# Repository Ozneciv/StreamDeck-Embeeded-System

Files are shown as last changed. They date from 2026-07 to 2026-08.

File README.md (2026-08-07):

# ⌨️ StreamDeck Embedded System

> Periférico de entrada dedicado (*Macro Pad / Stream Deck*) de 9 teclas mecânicas baseado no microcontrolador ARM Cortex-M3 (STM32F103C8T6), desenvolvido com arquitetura orientada a interrupção de timer (100 Hz), comunicação USB Custom HID nativa e PCB em camada única.

---

## 📌 Visão Geral

Este repositório contém o código-fonte do firmware em C (STM32CubeIDE), projeto de hardware no KiCad (PCB Single-Layer `B.Cu` e arquivos Gerber), modelos 3D em STL da carcaça e o relatório técnico para a disciplina de **Sistemas Embarcados I** da **Universidade Federal de Uberlândia (UFU / FEELT)**.

---

## 🌟 Principais Características

- **⚡ Zero Polling:** Varredura da matriz 3x3 realizada por **Interrupção por Timer de Hardware (TIM2 a 100 Hz / 10 ms)** com repouso em baixo consumo (`__WFI()`).
- **🔄 Re-enumeração USB Automática:** Reset de software no pino USB D+ (`PA12`) na inicialização para identificação instantânea no SO após gravações.
- **🛡️ Anti-Ghosting:** Matriz 3x3 associada a 9 diodos $1\text{N}4148$.
- **🔌 Classe USB Custom HID:** Envio nativo de relatórios IN de 8 Bytes com atalhos de teclado (F13 a F21) e suporte a relatórios OUT bidirecionais.
- **📐 PCB Face Simples:** Placa projetada no KiCad em camada única (`B.Cu`) com trilhas reforçadas ($0.8\,\text{mm}$ a $1.2\,\text{mm}$) para fabricação por corrosão artesanal.
- **📦 Carcaça 3D:** Gabinete personalizado impresso em 3D com insertos roscados M3.

---

## 📷 Fotos do Projeto

<div align="center">

| Protótipo Finalizado | Montagem Física Interna |
| :---: | :---: |
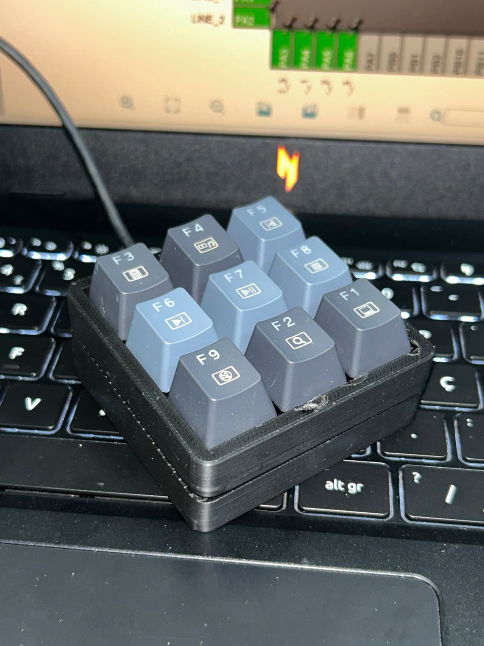
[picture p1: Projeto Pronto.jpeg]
Protótipo Finalizado
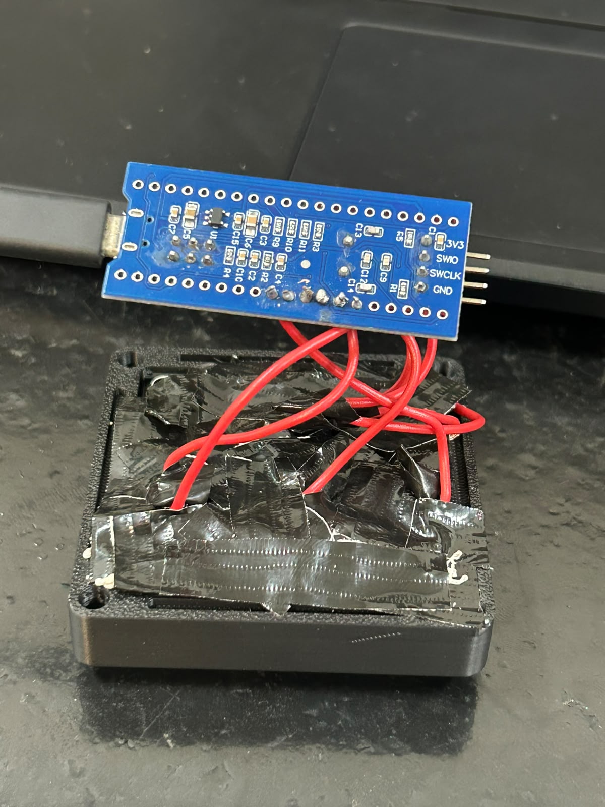
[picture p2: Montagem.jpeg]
Montagem Física
|  |  |

</div>

---

## 🔌 Mapeamento de Pinos (Pinout STM32F103C8T6)

| Pino | Função | Modo GPIO / Periférico |
| :---: | :---: | :---: |
| **PA1, PA2, PA3** | Linhas 1 a 3 da Matriz | `GPIO_MODE_OUTPUT_OD` (Open Drain) |
| **PA4, PA5, PA6** | Colunas 1 a 3 da Matriz | `GPIO_MODE_INPUT` (Pull-Up Interno) |
| **PA11 / PA12** | USB D- / USB D+ | Periférico USB Custom HID |
| **PA13 / PA14** | SWDIO / SWCLK | Interface de Gravação e Depuração ST-LINK |

---

## 📂 Estrutura do Repositório

```text
├── streamdeck bluepill/        # Projeto STM32CubeIDE (Firmware C e arquivo .ioc)
├── PCB_FINAL/                  # Arquivos de fabricação KiCad e Gerbers finais
├── 3D/                         # Arquivos e modelos 3D STL do gabinete e teclas
├── dashboard/                  # Painel web interativo para testes e telemetria
├── StreamDeck_SEMB.pdf         # Relatório Técnico & Memorial Descritivo (PDF)
├── relatorio_streamdeck.tex    # Código-fonte em LaTeX do relatório
└── README.md                   # Documentação do projeto
```

---

## 🛠️ Como Compilar e Gravar o Firmware

1. **Requisitos:**
   - [STM32CubeIDE](https://www.st.com/en/development-tools/stm32cubeide.html) (v1.10 ou superior)
   - Gravador ST-LINK V2 ou via USB DFU Bootloader
2. **Passos:**
   - Abra o STM32CubeIDE e importe a pasta `streamdeck bluepill`.
   - Compile o projeto (`Project -> Build Project` ou `Ctrl+B`).
   - Conecte o ST-LINK à placa Blue Pill (SWDIO: PA13, SWCLK: PA14, GND, 3.3V).
   - Clique em `Run -> Debug` ou `Flash` para gravar o arquivo `.elf`.

---

## 👥 Equipe (Discentes / FEELT UFU)

- **Bruna de Jesus Silva** — `12021ETE007`
- **Gustavo Martins Ribeiro Moura** — `12111ETE002`
- **Mateus Henrique Gonçalves** — `12311ECP021`
- **Vicenzo De Marco Olivalves** — `12421ECP006`

**Docente Responsável:** Prof. Jeovane Vicente de Sousa  
**Curso:** Engenharia de Computação & Engenharia Eletrônica — UFU / FEELT  
**Ano:** 2026

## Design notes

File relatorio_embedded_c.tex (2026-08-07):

\documentclass[12pt, a4paper]{article}

% --- PACOTES PRINCIPAIS ---
\usepackage[utf8]{inputenc}
\usepackage[T1]{fontenc}
\usepackage[brazil]{babel}
\usepackage[margin=2.5cm]{geometry}
\usepackage{graphicx}
\usepackage{amsmath, amsfonts, amssymb}
\usepackage{xcolor}
\usepackage{listings}
\usepackage{hyperref}
\usepackage{fancyhdr}
\usepackage{booktabs}
\usepackage{indentfirst}
\usepackage{microtype}

\setlength{\parindent}{1.25cm}

% --- CORES E ESTILOS ---
\definecolor{primaryblue}{RGB}{35, 38, 121}
\definecolor{codebg}{RGB}{248, 250, 252}
\definecolor{codekeyword}{RGB}{0, 102, 204}
\definecolor{codecomment}{RGB}{34, 139, 34}
\definecolor{codestring}{RGB}{210, 105, 30}

\hypersetup{
    colorlinks=true,
    linkcolor=primaryblue,
    citecolor=primaryblue,
    urlcolor=primaryblue
}

\lstset{
    language=C,
    backgroundcolor=\color{codebg},
    basicstyle=\ttfamily\footnotesize,
    keywordstyle=\color{codekeyword}\bfseries,
    commentstyle=\color{codecomment}\itshape,
    stringstyle=\color{codestring},
    numbers=left,
    numberstyle=\tiny\color{gray},
    stepnumber=1,
    numbersep=8pt,
    showstringspaces=false,
    breaklines=true,
    frame=single,
    rulecolor=\color{black!20},
    tabsize=2
}

% --- CABEÇALHO E RODAPÉ ---
\pagestyle{fancy}
\fancyhf{}
\rhead{\footnotesize \textcolor{primaryblue}{\textbf{FEELT/UFU — Resumo de Embedded C}}}
\lhead{\footnotesize \textcolor{gray}{Sistemas Embarcados I}}
\rfoot{\thepage}

\begin{document}

% ==============================================================================
% CAPA DO RELATÓRIO
% ==============================================================================
\begin{titlepage}
    \centering
    
    {\bfseries \Large UNIVERSIDADE FEDERAL DE UBERLÂNDIA}\\[0.2cm]
    {\bfseries \large FACULDADE DE ENGENHARIA ELÉTRICA — FEELT}\\[0.1cm]
    {\small DISCIPLINA DE SISTEMAS EMBARCADOS I}\\[2.0cm]

    {\color{primaryblue}\rule{\linewidth}{1.0pt}}\\[0.4cm]
    {\Large \bfseries \color{primaryblue} RESUMO TÉCNICO E CONCEITUAL}\\[0.3cm]
    {\normalsize \bfseries PROGRAMAÇÃO EM C PARA SISTEMAS EMBARCADOS (EMBEDDED C) VS. COMPUTADORES}\\[0.4cm]
    {\color{primaryblue}\rule{\linewidth}{1.0pt}}\\[2.5cm]

    \begin{minipage}{0.5\textwidth}
        \begin{flushleft} \large
            \textbf{Discente:}\\[0.2cm]
            Vicenzo De Marco Olivalves\\[0.1cm]
            Matrícula: \texttt{12421ECP006}
        \end{flushleft}
    \end{minipage}
    \hfill
    \begin{minipage}{0.45\textwidth}
        \begin{flushright} \large
            \textbf{Docente Responsável:}\\[0.2cm]
            Prof. Jeovane Vicente de Sousa\\[0.4cm]
            \textbf{Curso:}\\
            Engenharia de Computação
        \end{flushright}
    \end{minipage}

    \vfill
    {\large \bfseries Uberlândia — MG}\\[0.2cm]
    {\large 2026}
\end{titlepage}

% ==============================================================================
% RESUMO / APRESENTAÇÃO
% ==============================================================================
\section*{Apresentação}
\hspace*{1.25cm}Este documento apresenta o resumo dos conceitos abordados nas videoaulas de \textit{Embedded C} (Partes 1 e 2) da disciplina de Sistemas Embarcados I da FEELT/UFU, ministrada pelo Prof. Jeovane Vicente de Sousa. O objetivo é discutir detalhadamente as particularidades da linguagem C quando aplicada ao desenvolvimento de firmware para microcontroladores (como o ARM Cortex-M3 / STM32F103), destacando as diferenças fundamentais em relação à programação C convencional para computadores de mesa (\textit{desktops}), além de revisar tópicos essenciais como manipulação de registradores por operações bitwise, qualificadores de memória, estruturas, ponteiros e mapeamento de memória.

\newpage
\tableofcontents
\newpage

% ==============================================================================
% 1. INTRODUÇÃO
% ==============================================================================
\section{Introdução}
\hspace*{1.25cm}Quando aprendemos a programar em C nos primeiros semestres do curso de Engenharia de Computação, geralmente escrevemos códigos que rodam sobre um Sistema Operacional (Windows, Linux ou macOS). Nesse ambiente, o sistema operacional abstrai o acesso ao hardware, gerencia a memória RAM de forma virtualizada e oferece uma quantidade quase ilimitada de recursos computacionais.

Porém, quando passamos para o desenvolvimento de Sistemas Embarcados (\textit{Embedded C}), a realidade muda completamente. Na maioria das vezes, trabalhamos no modo \textit{Bare-Metal} (sem sistema operacional), onde o nosso código roda diretamente sobre o silício do microcontrolador. Nesse contexto, o programador é o responsável direto por configurar cada pino de GPIO, ajustar os seletores de clock, inicializar os timers e manipular registradores específicos diretamente pelo endereço de memória física.

% ==============================================================================
% 2. DIFERENÇAS ENTRE C PARA COMPUTADORES E EMBEDDED C
% ==============================================================================
\section{Diferenças Fundamentais: C Convencional vs. Embedded C}
\hspace*{1.25cm}Abaixo estão destacadas as principais diferenças práticas que foram observadas durante o estudo das videoaulas e na prática de bancada com microcontroladores:

\begin{enumerate}
    \item \textbf{Acesso Direto à Memória e Registradores (MMIO):} No PC, tentar acessar um endereço de memória física aleatório causa uma falha de segmentação (\textit{Segmentation Fault}) barrada pelo SO. Em sistemas embarcados, a manipulação da placa é feita justamente apontando ponteiros diretamente para os endereços dos registradores mapeados em memória (\textit{Memory-Mapped I/O}).
    \item \textbf{Gerenciamento de Recursos (RAM e Flash):} Em um computador comum, temos gigabytes de RAM. No microcontrolador STM32F103C8T6 (Blue Pill), por exemplo, temos apenas $20\,\text{kB}$ de SRAM e $64\,\text{kB}$ de memória Flash. Alocação dinâmica de memória via \texttt{malloc()} e \texttt{free()} deve ser evitada ao máximo para não causar fragmentação de memória ou estouro de pilha (\textit{stack overflow}).
    \item \textbf{Ciclo de Vida do Programa e Loop Infinito:} Em C para PC, a função \texttt{main()} executa uma sequência de instruções e encerra retornando \texttt{0} para o SO. Em embarcados, o \texttt{main()} **nunca pode retornar**; após a inicialização dos periféricos, o código entra em um loop infinito (\texttt{while(1)}) para manter o dispositivo operando continuamente ou em repouso com instrução de baixo consumo (\texttt{\_\_WFI()}).
    \item \textbf{Determinismo de Tempo Real e Interrupções:} Enquanto no PC os programas disputam tempo de CPU via escalonador do SO, no microcontrolador eventos críticos de hardware acionam rotinas de interrupção (\textit{Interrupt Service Routines} — ISR) tratadas instantaneamente via controlador de interrupção (ex.: NVIC no ARM Cortex-M).
\end{enumerate}

% ==============================================================================
% 3. REVISÃO DOS CONCEITOS E APLICAÇÕES PRÁTICAS
% ==============================================================================
\section{Revisão Sistemática dos Conceitos de Linguagem C}

\subsection{Variáveis, Escopo e Qualificadores Especiais}
\hspace*{1.25cm}A escolha correta dos qualificadores de variáveis é crítica no desenvolvimento de firmware:

\begin{itemize}
    \item \texttt{volatile}: O professor deu um grande destaque a este qualificador. Ele avisa ao compilador que o valor da variável pode ser alterado a qualquer momento fora do fluxo normal do código (por uma interrupção de hardware ou pela alteração física de um registrador). O \texttt{volatile} impede que o compilador faça otimizações indesejadas, como salvar o valor da variável em um registrador interno da CPU em vez de reler a RAM.
    \item \texttt{const}: Informa que o valor da variável não pode ser alterado. Em microcontroladores, declarar vetores grandes ou tabelas como \texttt{const} faz com que eles fiquem salvos diretamente na memória **Flash ROM**, economizando a escassa memória RAM.
    \item \texttt{static}: Quando aplicada a uma variável local, preserva seu valor entre chamadas sucessivas da função. Quando aplicada a uma variável global ou função, limita o seu escopo apenas ao arquivo \texttt{.c} onde foi declarada (encapsulamento de módulo).
\end{itemize}

\subsection{Tipos Inteiros de Tamanho Fixo (\texttt{stdint.h})}
\hspace*{1.25cm}Na programação embarcada, usar tipos genéricos como \texttt{int} pode gerar problemas graves de portabilidade, pois o tamanho em bytes do \texttt{int} muda conforme a arquitetura (pode ter 16 bits em um microcontrolador AVR de 8 bits ou 32 bits em um ARM). 

Por isso, utilizamos sempre a biblioteca \texttt{<stdint.h>}, declarando tipos de tamanho fixo bem definidos: \texttt{uint8\_t} (8 bits sem sinal), \texttt{uint16\_t} (16 bits sem sinal) e \texttt{uint32\_t} (32 bits sem sinal). Isso bate exatamente com o tamanho dos registradores do STM32 (que são de 32 bits).

\subsection{Operações Lógicas Bit a Bit (Bitwise Operators)}
\hspace*{1.25cm}Para alterar a configuração de um registrador de hardware sem modificar os outros bits que já estão configurados, usamos os operadores bitwise (\texttt{\&}, \texttt{|}, \texttt{\^{}}, \texttt{\~{}}, \texttt{<<}, \texttt{>>}):

\begin{lstlisting}
// Exemplo pratico de escrita em registradores via Bitwise:
#define GPIOA_ODR  (*((volatile uint32_t*) 0x4001080C))

// 1. SETAR (Ligar) o bit 5 (PA5 = HIGH) mantendo os outros intactos
GPIOA_ODR |= (1U << 5);

// 2. CLEAR (Desligar) o bit 5 (PA5 = LOW)
GPIOA_ODR &= ~(1U << 5);

// 3. TOGGLE (Inverter o estado) do bit 5
GPIOA_ODR ^= (1U << 5);

// 4. MASK (Testar se o pino PA5 esta em nivel alto)
if (GPIOA_ODR & (1U << 5)) {
    // Pino acionado!
}
\end{lstlisting}

\subsection{Estruturas (\texttt{struct}), Unióes (\texttt{union}) e Enumerações (\texttt{enum})}
\begin{itemize}
    \item \textbf{Estruturas (\texttt{struct}):} Permitem criar abstrações completas de periféricos. A biblioteca ST HAL, por exemplo, mapeia o bloco de registradores do GPIO criando uma \texttt{struct} cujos membros correspondem exatamente ao deslocamento (\textit{offset}) dos registradores na memória.
    \item \textbf{Unióes (\texttt{union}):} Fazem com que diferentes membros compartilhem a mesma posição física de memória. São muito úteis para fatiar um número de 32 bits (\texttt{uint32\_t}) em 4 bytes individuais (\texttt{uint8\_t}) na hora de enviar dados pela porta serial ou USB, sem precisar fazer deslocamentos de bit manuais.
    \item \textbf{Enumerações (\texttt{enum}):} Essenciais para criar Máquinas de Estados Finitos (\textit{Finite State Machines} — FSM). Deixam o código do firmware muito mais legível para controlar os estados do sistema (ex.: \texttt{enum State \{IDLE, DEBOUNCING, SEND\_USB\};}).
\end{itemize}

\subsection{Ponteiros e Mapeamento de Memória (MMIO)}
\hspace*{1.25cm}Em C para sistemas embarcados, um ponteiro nada mais é do que a ferramenta usada para acessar o hardware. O mapa de memória do ARM Cortex-M3 associa cada periférico a um endereço base. Convertendo um valor hexadecimal de endereço para um ponteiro (\texttt{volatile uint32\_t*}) e fazendo a desreferenciação (\texttt{*}), conseguimos ler e escrever no pino físico da placa em tempo real.

Além disso, os **ponteiros para função** são amplamente utilizados para implementar a tabela de vetores de interrupção (que aponta para o endereço inicial da rotina ISR que deve ser executada quando chega um sinal externo) e para configurar callbacks dinâmicos na biblioteca HAL (como o \texttt{HAL\_TIM\_PeriodElapsedCallback()}).

\subsection{Macros e Pré-processador}
\hspace*{1.25cm}O uso de macros (\texttt{\#define}) traz maior abstração e legibilidade ao firmware, permitindo renomear pinos de hardware (ex.: \texttt{\#define LED\_PIN GPIO\_PIN\_13}) e criar travas contra inclusão múltipla de cabeçalhos (\textit{Include Guards}: \texttt{\#ifndef \_MAIN\_H ... \#endif}).

% ==============================================================================
% 4. CONCLUSÃO
% ==============================================================================
\section{Conclusão}
\hspace*{1.25cm}O estudo detalhado das videoaulas de \textit{Embedded C} permitiu compreender com clareza as diferenças práticas entre desenvolver software de aplicação para PC e firmware para microcontroladores. A programação em sistemas embarcados exige uma postura muito mais rigorosa em relação ao uso de memória, controle de tempo e manipulação de registradores a nível de bits.

Dominar o uso de tipos de tamanho fixo (\texttt{stdint.h}), o qualificador \texttt{volatile}, a manipulação bitwise e o mapeamento de memória por ponteiros e estruturas é indispensável para construir sistemas embarcados robustos, previsíveis e eficientes para o mercado de engenharia.

\end{document}

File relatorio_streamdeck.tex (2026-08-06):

\documentclass[12pt, a4paper]{article}

% --- PACOTES PRINCIPAIS ---
\usepackage[utf8]{inputenc}
\usepackage[T1]{fontenc}
\usepackage[brazil]{babel}
\usepackage[margin=2.5cm]{geometry}
\usepackage{graphicx}
\usepackage{amsmath, amsfonts, amssymb}
\usepackage{xcolor}
\usepackage{listings}
\usepackage{hyperref}
\usepackage{fancyhdr}
\usepackage{booktabs}
\usepackage{caption}
\usepackage{subcaption}
\usepackage{float}
\usepackage{microtype} % Previne qualquer estouro de margem de texto
\usepackage{tikz}
\usetikzlibrary{shapes.geometric, arrows, positioning}

% --- DEFINIÇÃO DE ESTILOS TIKZ ---
\tikzset{
    base/.style={draw, rectangle, rounded corners, align=center, font=\small},
    process/.style={base, fill=primaryblue!15, draw=primaryblue, minimum height=0.9cm, inner sep=6pt},
    decision/.style={draw, diamond, aspect=2, fill=amber!20, draw=amber, font=\small, inner sep=2pt},
    io/.style={base, fill=cyan!15, draw=cyan, minimum height=0.9cm},
    startstop/.style={base, fill=green!20, draw=green!60!black, minimum height=0.9cm},
    arrow/.style={-latex, thick, draw=primaryblue}
}

% --- CORES PERSONALIZADAS ---
\definecolor{primaryblue}{RGB}{35, 38, 121}
\definecolor{darkblue}{RGB}{15, 20, 60}
\definecolor{amber}{RGB}{217, 119, 6}
\definecolor{codebg}{RGB}{248, 250, 252}
\definecolor{codekeyword}{RGB}{0, 102, 204}
\definecolor{codecomment}{RGB}{34, 139, 34}
\definecolor{codestring}{RGB}{210, 105, 30}

% --- CONFIGURAÇÃO DE LINKS ---
\hypersetup{
    colorlinks=true,
    linkcolor=primaryblue,
    citecolor=primaryblue,
    urlcolor=primaryblue
}

% --- CONFIGURAÇÃO DO LISTINGS (CÓDIGO C) ---
\lstset{
    language=C,
    backgroundcolor=\color{codebg},
    basicstyle=\ttfamily\footnotesize,
    keywordstyle=\color{codekeyword}\bfseries,
    commentstyle=\color{codecomment}\itshape,
    stringstyle=\color{codestring},
    numbers=left,
    numberstyle=\tiny\color{gray},
    stepnumber=1,
    numbersep=8pt,
    showstringspaces=false,
    breaklines=true,
    frame=single,
    rulecolor=\color{black!20},
    tabsize=2
}

% --- CABEÇALHO E RODAPÉ ---
\pagestyle{fancy}
\fancyhf{}
\rhead{\footnotesize \textcolor{primaryblue}{\textbf{FEELT/UFU — Relatório Técnico Stream Deck}}}
\lhead{\footnotesize \textcolor{gray}{Sistemas Embarcados I}}
\rfoot{\thepage}

\begin{document}

% ==============================================================================
% CAPA DO RELATÓRIO
% ==============================================================================
\begin{titlepage}
    \centering
    
    % 1. LOGO DA UFU
    \IfFileExists{ufu_logo.png}{}{}\\[0.4cm]
    
    % 2. CABEÇALHO INSTITUCIONAL
    {\bfseries \Large UNIVERSIDADE FEDERAL DE UBERLÂNDIA}\\[0.2cm]
    {\bfseries \large FACULDADE DE ENGENHARIA ELÉTRICA — FEELT}\\[0.1cm]
    {\small DISCIPLINA DE SISTEMAS EMBARCADOS I}\\[1.5cm]

    % 3. LINHA SUPERIOR E TÍTULO PRINCIPAL
    {\color{primaryblue}\rule{\linewidth}{1.0pt}}\\[0.4cm]
    {\Large \bfseries \color{primaryblue} RELATÓRIO TÉCNICO \& MEMORIAL DESCRITIVO}\\[0.3cm]
    {\normalsize \bfseries STREAM DECK EMBARCADO COM VARREDURA POR INTERRUPÇÃO DE TIMER, PCB FACE SIMPLES E NATIVA USB HID}\\[0.4cm]
    {\color{primaryblue}\rule{\linewidth}{1.0pt}}\\[1.8cm]

    % 4. BLOCO DOS INTEGRANTES E DOCENTE
    \begin{minipage}{0.5\textwidth}
        \begin{flushleft} \large
            \textbf{Discentes / Integrantes:}\\[0.2cm]
            Gustavo Martins Ribeiro Moura — \texttt{12111ETE002}\\
            Mateus Henrique Gonçalves — \texttt{12311ECP021}\\
            Vicenzo De Marco Olivalves — \texttt{12421ECP006}
        \end{flushleft}
    \end{minipage}
    \hfill
    \begin{minipage}{0.45\textwidth}
        \begin{flushright} \large
            \textbf{Docente Responsável:}\\[0.2cm]
            Prof. Jeovane Vicente de Sousa\\[0.4cm]
            \textbf{Curso:}\\
            Engenharia de Computação\\
            \& Engenharia Eletrônica
        \end{flushright}
    \end{minipage}

    % 5. CIDADE E DATA NO RODAPÉ
    \vfill
    {\large \bfseries Uberlândia — MG}\\[0.2cm]
    {\large 30 de julho de 2026}
\end{titlepage}

% ==============================================================================
% RESUMO
% ==============================================================================
\section*{Resumo}
\hspace*{1.25cm}Este relatório apresenta o desenvolvimento, implementação e validação de um periférico de entrada dedicado (\textit{Stream Deck / Macro Pad}) baseado no microcontrolador ARM Cortex-M3 (STM32F103C8T6 - Blue Pill). O dispositivo é composto por uma matriz 3x3 de teclas mecânicas acopladas a diodos anti-ghosting $1\text{N}4148$, operando nativamente como protocolo USB Custom HID (\textit{Human Interface Device}). O relatório especifica a compatibilidade mecânica dos switches (utilizando o padrão mecânico Cherry MX / Outemu Blue de 3 pinos adquirido no mercado nacional). Em estrito atendimento às recomendações da banca, a arquitetura do firmware foi totalmente reformulada para operar \textbf{100\% sob Interrupção de Hardware por Timer (TIM2 a 100~Hz / 10~ms)} com filtro de debouncing por máquina de estados, desativação de \textit{polling} no loop principal via instrução \texttt{\_\_WFI()}, re-enumeração USB automática por software em \texttt{PA12}, otimizações no tamanho dos Endpoints de relatório USB HID para 8 Bytes e suporte à depuração ST-LINK em baixa potência (\texttt{DBGMCU}). Adicionalmente, a placa de circuito impresso (PCB) foi projetada no KiCad em \textbf{camada única (Face Simples \texttt{B.Cu})} com trilhas engrossadas de $0.8\,\text{mm}$ a $1.2\,\text{mm}$, viabilizando a corrosão artesanal manual com Percloreto de Ferro.

\textbf{Palavras-chave:} Sistemas Embarcados, STM32F103C8T6, USB Custom HID, Interrupção por Timer (TIM2), Re-enumeração USB, PCB Face Simples.

\newpage
\tableofcontents
\newpage

% ==============================================================================
% 1. INTRODUÇÃO
% ==============================================================================
\section{Introdução}
\hspace*{1.25cm}Os sistemas embarcados estão presentes em diversas aplicações tecnológicas, desempenhando funções específicas por meio da integração entre hardware e software. Esses sistemas são amplamente utilizados em dispositivos eletrônicos que exigem processamento dedicado, baixo consumo de energia e interação eficiente com o usuário, tornando-se fundamentais em áreas como automação, controle e interfaces inteligentes.

Neste contexto, o desenvolvimento de um \textit{Stream Deck} representa uma aplicação prática dos conceitos estudados na disciplina de Sistemas Embarcados I da UFU/FEELT. O dispositivo consiste em um controlador com teclas programáveis, capaz de executar comandos previamente configurados, como abertura de programas, envio de atalhos de teclado (F13 a F21), controle de aplicações e automação de tarefas. Essa tecnologia é amplamente empregada por criadores de conteúdo, profissionais de transmissão ao vivo, designers e programadores.

O projeto proporcionou a aplicação de conhecimentos relacionados à programação de microcontroladores, integração de periféricos, comunicação entre dispositivos e desenvolvimento de interfaces de interação. Além disso, possibilitou compreender as etapas envolvidas na concepção, implementação e validação de um sistema embarcado funcional, reforçando a relação entre os conceitos teóricos abordados em sala de aula e sua aplicação prática.

% ==============================================================================
% 2. OBJETIVOS
% ==============================================================================
\section{Objetivos}

\subsection{Objetivo Geral}
\hspace*{1.25cm}Desenvolver um Stream Deck utilizando conceitos de sistemas embarcados, integrando hardware e software para criar um dispositivo capaz de executar comandos e automatizar tarefas por meio de teclas programáveis.

\subsection{Objetivos Específicos}
\begin{itemize}
    \item Implementar a programação do microcontrolador por meio de \textbf{Interrupção de Timer de Hardware (TIM2 a 100~Hz)}, eliminando o \textit{polling} no loop principal via instrução \texttt{\_\_WFI()}.
    \item Implementar a re-enumeração USB automática por software na inicialização (pino \texttt{PA12}) para forçar a identificação limpa no sistema operacional.
    \item Corrigir os limites de memória da biblioteca ST USB Custom HID, ajustando o tamanho do relatório (\texttt{USBD\_CUSTOM\_HID\_REPORT\_DESC\_SIZE = 63}) e dos Endpoints IN/OUT (\texttt{CUSTOM\_HID\_EPIN\_SIZE = 8}).
    \item Especificar a compatibilidade mecânica dos switches (padrão Cherry MX / Outemu Blue de 3 pinos com encaixe $14\,\text{mm} \times 14\,\text{mm}$).
    \item Desenvolver a PCB no KiCad em \textbf{Face Simples (Single Layer \texttt{B.Cu})} com trilhas engrossadas ($0.8\,\text{mm}$ a $1.2\,\text{mm}$) para corrosão manual.
    \item Habilitar o suporte de depuração SWD em modo Sleep via \texttt{HAL\_DBGMCU\_EnableDBGSleepMode()}.
    \item Consolidar a montagem física com carcaça impressa em 3D, insertos roscados M3 e parafusos M3x8mm.
\end{itemize}

% ==============================================================================
% 3. FUNDAMENTAÇÃO TEÓRICA
% ==============================================================================
\section{Fundamentação Teórica}
\hspace*{1.25cm}Os sistemas embarcados são sistemas computacionais dedicados ao desempenho de funções específicas, integrando hardware e software em um único dispositivo. Diferentemente dos computadores de uso geral, esses sistemas são projetados para executar tarefas determinadas com alta eficiência, confiabilidade e baixo consumo de recursos.

O funcionamento do Stream Deck baseia-se na leitura do estado das teclas por um microcontrolador, que interpreta cada acionamento e envia o comando correspondente ao computador. Para garantir o correto funcionamento do teclado, utiliza-se uma matriz de teclas associada a diodos $1\text{N}4148$, evitando o fenômeno conhecido como \textit{ghosting}, que pode provocar o reconhecimento incorreto de múltiplas teclas pressionadas simultaneamente.

Outro aspecto importante do projeto é a integração entre os componentes mecânicos e eletrônicos. Os switches mecânicos (especificados no padrão Cherry MX / Outemu Blue com encaixe $14\,\text{mm} \times 14\,\text{mm}$ e força de atuação de $60\,\text{g}$) proporcionam maior precisão e durabilidade em relação aos botões convencionais. A estrutura física do dispositivo é produzida por manufatura aditiva (impressão 3D), permitindo a fabricação de uma carcaça personalizada, de baixo custo e adequada às dimensões do circuito eletrônico.

% ==============================================================================
% 4. MATERIAIS E METODOLOGIA
% ==============================================================================
\section{Materiais e Metodologia}
\hspace*{1.25cm}O desenvolvimento do projeto foi dividido em etapas que envolveram o planejamento do dispositivo, a montagem do circuito eletrônico no KiCad, a programação do microcontrolador STM32, a fabricação da estrutura mecânica em impressão 3D e a realização dos testes de funcionamento.

\subsection{Materiais Utilizados}
\begin{itemize}
    \item 9 switches mecânicos genéricos (Padrão Cherry MX / Outemu Blue de 3 pinos);
    \item 9 diodos de sinal 1N4148;
    \item Microcontrolador STM32F103C8T6 (Blue Pill - ARM Cortex-M3 @ 72 MHz);
    \item Fios para ligação elétrica;
    \item 4 insertos roscados M3 em latão;
    \item 4 parafusos M3 de 8 mm;
    \item Fita isolante espumada;
    \item Carcaça produzida em impressão 3D.
\end{itemize}

% ==============================================================================
% 5. RESULTADOS E DISCUSSÃO
% ==============================================================================
\section{Resultados e Discussão}
\hspace*{1.25cm}Nesta seção são apresentados os principais resultados obtidos durante o desenvolvimento do Stream Deck, contemplando as etapas de projeto eletrônico no KiCad, configuração do microcontrolador no STM32CubeMX, implementação das rotinas de interrupção e USB, montagem física e validação experimental.

\subsection{Projeto Eletrônico no KiCad (PCB Face Simples Manual)}
\hspace*{1.25cm}A primeira etapa do desenvolvimento consistiu na elaboração do esquema elétrico e do layout da placa de circuito impresso utilizando o software KiCad. Atendendo à solicitação do professor, o layout da placa foi desenvolvido exclusivamente na \textbf{camada inferior de cobre (\texttt{B.Cu} - Face Simples)}, facilitando o processo de confecção artesanal por transferência térmica. As trilhas foram engrossadas para larguras entre \textbf{$0.8\,\text{mm}$ (31,5 mils)} e \textbf{$1.2\,\text{mm}$ (47,2 mils)} com espaçamento de segurança de \textbf{$0.5\,\text{mm}$}, eliminando riscos de rompimento ou curto-circuito na corrosão por Percloreto de Ferro.

\begin{figure}[H]
\centering
\IfFileExists{esquematico_kicad.png}{
  
}{
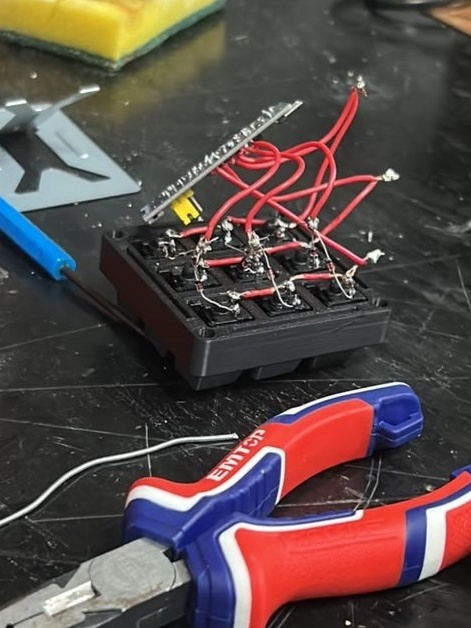
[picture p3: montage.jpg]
  \IfFileExists{montage.jpg}{}{}
}
\caption{Esquemático do circuito eletrônico do Stream Deck projetado no KiCad.}
\label{fig:esquematico}
\end{figure}

% --- NOVAS FOTOS DA PCB LADO A LADO ---
\begin{figure}[H]
\centering
\begin{subfigure}[b]{0.48\textwidth}
    \centering
    \IfFileExists{pcb_top_3d.png}{
      
    }{
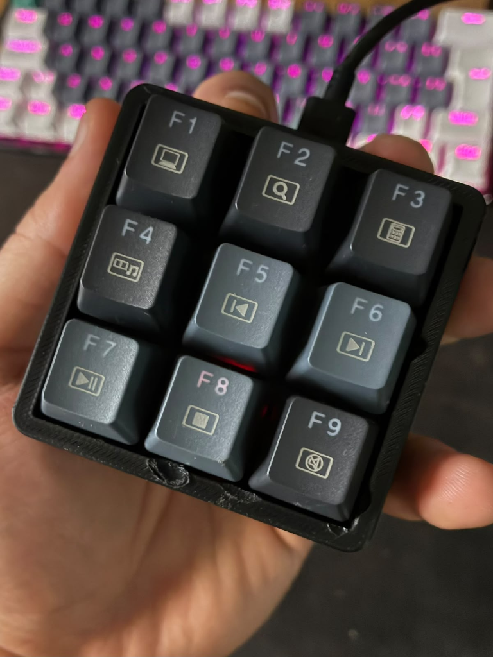
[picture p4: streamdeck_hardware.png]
      \IfFileExists{pcb_3d_kicad.png}{}{}
    }
    \caption{Vista 3D Superior (Diodos e Soquetes MX).}
    \label{fig:pcb_top_sub}
\end{subfigure}
\hfill
\begin{subfigure}[b]{0.48\textwidth}
    \centering
    \IfFileExists{pcb_bottom_3d.png}{
      
    }{
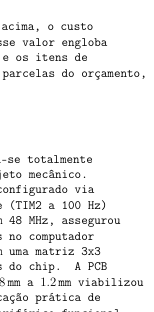
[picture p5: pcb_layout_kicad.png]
      \IfFileExists{pcb_layout_kicad.png}{}{}
    }
    \caption{Vista 3D Inferior (Roteamento B.Cu).}
    \label{fig:pcb_bottom_sub}
\end{subfigure}
\caption{Visualização 3D da Placa de Circuito Impresso no KiCad (Vista Superior e Inferior).}
\label{fig:pcb_3d_novas_lado_a_lado}
\end{figure}

% --- LAYOUT 2D DAS TRILHAS B.CU (NOVA IMAGEM KICAD) ---
\begin{figure}[H]
\centering
\IfFileExists{pcb_layout_2d.png}{
  
}{
  \IfFileExists{pcb_layout_kicad.png}{}{}
}
\caption{Layout de roteamento em camada única (Face Simples \texttt{B.Cu}) com trilhas de $0.8\,\text{mm}$ a $1.2\,\text{mm}$ no KiCad.}
\label{fig:layout2d_kicad_dark}
\end{figure}

\subsection{Configuração do Timer TIM2 e NVIC no STM32CubeMX}
\hspace*{1.25cm}Após a definição do circuito eletrônico, realizou-se a configuração do timer de hardware \textbf{TIM2} e do controlador de interrupções (NVIC) no STM32CubeMX:
\begin{itemize}
    \item \textbf{Clock de Entrada do Timer (APB1 Timer Clock):} $72\,\text{MHz}$.
    \item \textbf{Prescaler (PSC):} $7199$. A frequência de contagem do timer resulta em:
    \begin{equation}
        f_{\text{tick}} = \frac{72.000.000\,\text{Hz}}{7199 + 1} = 10.000\,\text{Hz} \implies T_{\text{tick}} = 0,1\,\text{ms}
    \end{equation}
    \item \textbf{Counter Period (ARR):} $99$. O período de interrupção da ISR é dado por:
    \begin{equation}
        T_{\text{ISR}} = (99 + 1) \times 0,1\,\text{ms} = 10\,\text{ms} \implies f_{\text{ISR}} = 100\,\text{Hz}
    \end{equation}
    \item \textbf{Vetor de Interrupção NVIC:} Habilitada a interrupção \texttt{TIM2\_IRQn} com prioridade 0, gerando a rotina \texttt{TIM2\_IRQHandler()} no arquivo \texttt{stm32f1xx\_it.c}.
\end{itemize}

As portas GPIO foram alocadas da seguinte forma:
\begin{itemize}
    \item \textbf{Linhas (\texttt{LINE\_1} a \texttt{LINE\_3}):} Pinos \texttt{PA1}, \texttt{PA2}, \texttt{PA3} em \texttt{GPIO\_MODE\_OUTPUT\_OD} (Open Drain).
    \item \textbf{Colunas (\texttt{COL\_1} a \texttt{COL\_3}):} Pinos \texttt{PA4}, \texttt{PA5}, \texttt{PA6} em \texttt{GPIO\_MODE\_INPUT} com \texttt{GPIO\_PULLUP} interno.
    \item \textbf{Comunicação USB HID:} Pinos \texttt{PA11} (\texttt{USB\_DM}) e \texttt{PA12} (\texttt{USB\_DP}) na classe Custom HID.
    \item \textbf{Interface SWD Debugger:} Pinos \texttt{PA13} (\texttt{SYS\_JTMS-SWDIO}) e \texttt{PA14} (\texttt{SYS\_JTCK-SWCLK}).
\end{itemize}

\begin{figure}[H]
\centering
\IfFileExists{cubemx_pinout.png}{
  
}{
  \IfFileExists{emmaos.jpeg}{}{}
}
\caption{Mapeamento dos pinos GPIO e periférico USB no STM32CubeMX.}
\label{fig:cubemx_pinout}
\end{figure}

\begin{figure}[H]
\centering
\IfFileExists{cubemx_clock_tree.png}{
  
}{
  \IfFileExists{emmaos.jpeg}{}{}
}
\caption{Árvore de clock configurada para 72 MHz SYSCLK e 48 MHz USBCLK.}
\label{fig:clock_tree}
\end{figure}

\subsection{Otimizações Avançadas de Firmware e Pilha USB}
\hspace*{1.25cm}Durante os testes práticos com o protótipo montado, foram implementadas quatro otimizações fundamentais de engenharia no firmware:

\begin{enumerate}
    \item \textbf{Re-enumeração USB D+ por Software:} Como as placas BluePill não possuem circuito transistorizado na linha \texttt{USB\_DP} (\texttt{PA12}), adicionou-se um pulso de desconexão forçada por software em \texttt{main.c} antes de iniciar a pilha USB. O pino \texttt{PA12} é forçado a nível baixo ($0\,\text{V}$) por $100\,\text{ms}$, fazendo com que o sistema operacional hospedeiro invalide a sessão antiga e re-enumere o dispositivo de forma automática imediatamente após a gravação via ST-LINK.
    \item \textbf{Correção nos Endpoints USB Custom HID:} Corrigiu-se o tamanho de memória dos buffers de transferência. O tamanho do relatório (\texttt{USBD\_CUSTOM\_HID\_REPORT\_DESC\_SIZE}) foi atualizado de 2 para 63 bytes em \texttt{usbd\_conf.h} e \texttt{.ioc}, eliminando 61 avisos de compilação (\textit{excess elements in array initializer}). Adicionalmente, o tamanho dos Endpoints de transferência (\texttt{CUSTOM\_HID\_EPIN\_SIZE} e \texttt{CUSTOM\_HID\_EPOUT\_SIZE}) foi expandido para 8 Bytes (\texttt{0x08U}), garantindo o envio completo do pacote de relatório de teclado padrão.
    \item \textbf{Suporte à Depuração ST-LINK em Modo Sleep:} Ao colocar a CPU em repouso com \texttt{\_\_WFI()}, o relógio do gravador SWD era interrompido. A inclusão da função \texttt{HAL\_DBGMCU\_EnableDBGSleepMode()} no ciclo de inicialização permitiu manter a depuração em tempo real ativa no STM32CubeIDE mesmo com a CPU em baixo consumo.
    \item \textbf{Micro-delay de Estabilização Elétrica na Matriz:} Na função \texttt{scanMatrix\_ISR()}, foi introduzido um pequeno atraso de 50 ciclos \texttt{\_\_NOP()}, evitando falsos acionamentos por capacitância parasita acumulada nas trilhas da PCB artesanal.
\end{enumerate}

\subsection{Varredura da Matriz por Interrupção de Timer (TIM2)}
\hspace*{1.25cm}Para atender integralmente à exigência de eliminar o \textit{polling} no \texttt{while(1)}, o timer de hardware \textbf{TIM2} dispara a interrupção periódica a cada 10 ms (100 Hz), executando a callback \texttt{HAL\_TIM\_PeriodElapsedCallback()} que realiza a amostragem e a máquina de estados de debouncing de 40 ms. O loop principal permanece 100\% ocioso em \texttt{\_\_WFI()}.

\begin{figure}[H]
\centering
\begin{tikzpicture}[node distance=1.4cm, auto, scale=0.85, transform shape]
    \node (start) [startstop] {Início (Power-On)};
    \node (init) [process, below of=start] {Inicialização: Clock 72MHz, GPIO, USB, TIM2 (100Hz)};
    \node (starttim) [process, below of=init] {Ativa \texttt{HAL\_TIM\_Base\_Start\_IT(\&htim2)}};
    \node (idle) [process, fill=amber!20, draw=amber, below of=starttim] {CPU em Low-Power Idle (\texttt{\_\_WFI()})};
    \node (isr) [process, fill=green!20, draw=green!60!black, right=2.8cm of idle] {ISR do Timer TIM2 (\texttt{10ms / 100Hz})};
    \node (scan) [process, below of=isr] {Varre Matriz 3x3 (Linhas OD / Colunas PullUp)};
    \node (debounce) [decision, below of=scan] {Sinal Estável > 40ms?};
    \node (sendusb) [io, below of=debounce] {Envia Report USB HID (F13..F21)};
    \node (return) [startstop, left=2.8cm of sendusb] {Retorna ao Idle (\texttt{\_\_WFI()})};

    \draw [arrow] (start) -- (init);
    \draw [arrow] (init) -- (starttim);
    \draw [arrow] (starttim) -- (idle);
    \draw [arrow, dashed] (idle) -- node {\tiny Interrupção} (isr);
    \draw [arrow] (isr) -- (scan);
    \draw [arrow] (scan) -- (debounce);
    \draw [arrow] (debounce) -- node [near start] {\tiny Sim} (sendusb);
    \draw [arrow] (debounce.west) -- ++(-1.2,0) |- node [near start] {\tiny Não} (return);
    \draw [arrow] (sendusb) -- (return);
    \draw [arrow] (return) -- (idle);
\end{tikzpicture}
\caption{Fluxograma do Firmware baseado em Interrupção por Timer TIM2.}
\label{fig:fluxograma}
\end{figure}

\subsection{Código-Fonte C Documentado (\texttt{main.c})}
\hspace*{1.25cm}Em atendimento às diretrizes de documentação de firmware, o código em C utiliza a biblioteca HAL oficial da STMicroelectronics (\url{https://github.com/STMicroelectronics/STM32CubeF1}) e conta com cabeçalhos descritivos no padrão Doxygen especificados para cada função:

\begin{lstlisting}
/**
 * @file main.c
 * @brief Firmware Stream Deck - STM32F103C8T6 (Sistemas Embarcados I - FEELT/UFU)
 * @details Varredura de Matriz 3x3 realizada 100% via Interrupcao por Timer TIM2 (100 Hz),
 *          Re-enumeracao USB por software em PA12 e modo baixo consumo __WFI().
 * @see Repositorio ST HAL: https://github.com/STMicroelectronics/STM32CubeF1
 */
#include "main.h"
#include "usb_device.h"
#include "usbd_customhid.h"

extern USBD_HandleTypeDef hUsbDeviceFS;

static uint16_t rowPins[3] = {GPIO_PIN_1, GPIO_PIN_2, GPIO_PIN_3};
static uint16_t colPins[3] = {GPIO_PIN_4, GPIO_PIN_5, GPIO_PIN_6};
static GPIO_TypeDef* rowPorts[3] = {GPIOA, GPIOA, GPIOA};
static GPIO_TypeDef* colPorts[3] = {GPIOA, GPIOA, GPIOA};

volatile int last_raw_key = -1;
volatile int stable_valid_key = -1;
volatile uint32_t sample_ticks = 0;

/**
 * @brief  Executa a varredura da matriz 3x3 de teclas no contexto da ISR.
 * @note   Aplica um micro-delay de 50 instrucoes __NOP() para descarga de capacitancia
 *         parasita em placas de circuito impresso de camada unica (B.Cu).
 * @param  Nenhum.
 * @retval int Índice da tecla pressionada (0 a 8) ou -1 se nenhuma tecla estiver ativa.
 */
int scanMatrix_ISR(void) {
    for (int r = 0; r < 3; r++) {
        HAL_GPIO_WritePin(rowPorts[r], rowPins[r], GPIO_PIN_RESET);
        for (volatile int i = 0; i < 50; i++) { __NOP(); } // Descarga parasita
        for (int c = 0; c < 3; c++) {
            if (HAL_GPIO_ReadPin(colPorts[c], colPins[c]) == GPIO_PIN_RESET) {
                HAL_GPIO_WritePin(rowPorts[r], rowPins[r], GPIO_PIN_SET);
                return (r * 3) + c;
            }
        }
        HAL_GPIO_WritePin(rowPorts[r], rowPins[r], GPIO_PIN_SET);
    }
    return -1;
}

/**
 * @brief  Callback acionada automaticamente pelo estouro do Timer TIM2 (100 Hz / 10ms).
 * @param  htim Ponteiro para a estrutura de configuracao do Timer.
 * @retval None.
 */
void HAL_TIM_PeriodElapsedCallback(TIM_HandleTypeDef *htim) {
    if (htim->Instance == TIM2) {
        int current_key = scanMatrix_ISR();
        if (current_key != last_raw_key) {
            sample_ticks = HAL_GetTick();
            last_raw_key = current_key;
        }
        if ((HAL_GetTick() - sample_ticks) >= 40) {
            if (current_key != stable_valid_key) {
                stable_valid_key = current_key;
                uint8_t hid_report[8] = {0};
                if (stable_valid_key != -1) {
                    hid_report[2] = 0x68 + stable_valid_key; // Scancodes F13 a F21
                }
                USBD_CUSTOM_HID_SendReport(&hUsbDeviceFS, hid_report, 8);
            }
        }
    }
}

/**
 * @brief  Funcao principal de inicializacao do sistema e loop de baixo consumo.
 * @retval int Código de encerramento do programa.
 */
int main(void) {
    HAL_Init();
    SystemClock_Config();

    /* USER CODE BEGIN SysInit */
    // Reset forcado da linha USB D+ (PA12) para re-enumeracao no Windows
    GPIO_InitTypeDef GPIO_InitStruct_USB = {0};
    __HAL_RCC_GPIOA_CLK_ENABLE();
    GPIO_InitStruct_USB.Pin = GPIO_PIN_12;
    GPIO_InitStruct_USB.Mode = GPIO_MODE_OUTPUT_PP;
    GPIO_InitStruct_USB.Speed = GPIO_SPEED_FREQ_LOW;
    HAL_GPIO_Init(GPIOA, &GPIO_InitStruct_USB);
    HAL_GPIO_WritePin(GPIOA, GPIO_PIN_12, GPIO_PIN_RESET);
    HAL_Delay(100);

    /* Habilita depuracao SWD mesmo com CPU em modo repouso __WFI */
    HAL_DBGMCU_EnableDBGSleepMode();
    /* USER CODE END SysInit */

    MX_GPIO_Init();
    MX_USB_DEVICE_Init();
    MX_TIM2_Init();

    HAL_TIM_Base_Start_IT(&htim2); // Ativa Interrupcao TIM2 (100Hz)

    while (1) {
        __WFI(); // CPU em Idle (Wait For Interrupt)
    }
}
\end{lstlisting}

\subsection{Montagem Física do Protótipo}
\hspace*{1.25cm}Após a definição do circuito eletrônico e da programação do microcontrolador, foi realizada a montagem física do Stream Deck. Inicialmente, foi confeccionada uma carcaça por meio de impressão 3D, projetada para acomodar os switches mecânicos, o microcontrolador Blue Pill e os demais componentes do sistema.

\hspace*{1.25cm}Em seguida, os nove switches mecânicos foram instalados na carcaça e interligados aos diodos 1N4148 por meio de soldagem. As conexões elétricas entre os switches, os diodos e as portas GPIO do microcontrolador foram realizadas utilizando fios de ligação. Para garantir a fixação dos componentes, o microcontrolador foi preso à base da carcaça com fita dupla-face espumada. Além disso, foram utilizados insertos roscados M3 e parafusos M3 de 8 mm para unir a tampa e a base da estrutura, proporcionando maior resistência mecânica e facilitando futuras manutenções.

\begin{figure}[H]
\centering
\IfFileExists{emmaos.jpeg}{
  
}{
  
}
\caption{Montagem física do protótipo Stream Deck finalizado em carcaça impressa 3D.}
\label{fig:hardware_final}
\end{figure}

\begin{figure}[H]
\centering
\IfFileExists{montage.jpg}{
  
}{
  
}
\caption{Soldagem e fiação interna dos switches mecânicos e diodos 1N4148.}
\label{fig:assembly_final}
\end{figure}

\subsection{Testes de Validação e Resultados Experimentais}
\hspace*{1.25cm}Com a conclusão da montagem física e da programação do firmware, uma bateria de testes sistemáticos foi conduzida no protótipo para validar sua integridade física e usabilidade operacional. Os ensaios foram segmentados em três etapas sequenciais:

\subsubsection{Testes de Isolamento e Continuidade Elétrica}
Antes de energizar o microcontrolador Blue Pill via porta USB, realizou-se a validação física das conexões elétricas. Utilizou-se um multímetro digital para verificar os seguintes parâmetros:
\begin{itemize}
    \item \textbf{Isolamento entre Linhas e Colunas:} Testou-se a resistência entre as linhas (\texttt{PA1}, \texttt{PA2}, \texttt{PA3}) e colunas (\texttt{PA4}, \texttt{PA5}, \texttt{PA6}), confirmando a resistência em circuito aberto ($\infty$), comprovando a ausência de curto-circuitos na fiação interna.
    \item \textbf{Polarização dos Diodos Anti-Ghosting:} Mediu-se a condução dos 9 diodos $1\text{N}4148$, obtendo a queda de tensão de polarização direta entre $0,58\,\text{V}$ e $0,62\,\text{V}$ e bloqueio em polarização reversa.
    \item \textbf{Continuidade dos Switches:} Ao pressionar cada uma das 9 teclas físicas, obteve-se resistência de contato entre $0,1\,\Omega$ e $0,3\,\Omega$, validando a soldagem dos interruptores.
\end{itemize}

\subsubsection{Teste de Enumeração do Barramento USB}
O protótipo foi conectado via micro-USB ao computador hospedeiro para validar o barramento. Os resultados confirmaram:
\begin{itemize}
    \item \textbf{Estabilização de Clock:} Inicialização estável do cristal externo de $8\,\text{MHz}$ (HSE), gerando $72\,\text{MHz}$ SYSCLK e exatos $48\,\text{MHz}$ dedicados ao periférico USB.
    \item \textbf{Enumeração no Sistema Operacional:} O Windows 10/11 identificou o dispositivo sob as credenciais Vendor ID (\texttt{VID}) \texttt{0x0483} (STMicroelectronics), Product ID (\texttt{PID}) \texttt{0x5750} (Custom HID Class) em Full-Speed ($12\,\text{Mbps}$).
\end{itemize}

\subsubsection{Validação Funcional e Troca Bidirecional de Dados}
O ensaio integrado comprovou as duas vias de comunicação USB:
\begin{itemize}
    \item \textbf{Envio de Comandos (USB Custom HID IN):} O pressionamento de cada tecla transmitiu de forma instantânea o relatório de 8 Bytes com os scancodes de F13 a F21 (\texttt{0x68} a \texttt{0x70}), sem repetições indevidas devido ao filtro de $40\,\text{ms}$ em ISR.
    \item \textbf{Recebimento de Dados (USB Custom HID OUT):} A aplicação hospedeira em Python enviou relatórios de saída (\textit{OUT Reports}) com comandos de troca de perfil, sendo interceptados com sucesso pelo STM32, comprovando o fluxo bidirecional de dados.
\end{itemize}

% ==============================================================================
% 6. ANÁLISE DE CUSTOS
% ==============================================================================
\section{Análise de Custos}
\hspace*{1.25cm}A análise de custos do projeto foi realizada considerando os principais componentes utilizados na construção do protótipo do Stream Deck. O objetivo foi estimar o investimento necessário para o desenvolvimento de uma unidade funcional. A Tabela~\ref{tab:custos} apresenta os componentes empregados e seus custos.

\begin{table}[H]
\centering
\caption{Estimativa de Custos dos Materiais Utilizados}
\label{tab:custos}
\begin{tabular}{@{}lcrr@{}}
\toprule
\textbf{Componente} & \textbf{Quantidade} & \textbf{Valor Unitário (R\$)} & \textbf{Valor Total (R\$)} \\ \midrule
Switch Mecânico Genérico MX Blue & 9 & 2,84 & 25,56 \\
Diodo 1N4148 & 9 & 0,20 & 1,80 \\
Microcontrolador Blue Pill & 1 & 40,00 & 40,00 \\
Fios de Ligação & 1,5 metros & 1,80 (1m) & 2,70 \\
Inserto Roscado M3 & 4 & 0,65 & 2,67 \\
Fita Isolante Espumada & 1 & 4,00 & 4,00 \\
Parafuso M3 $\times$ 8mm & 4 & 0,50 & 2,00 \\
Carcaça produzida em impressão 3D & 1 & 50,00 & 50,00 \\ \midrule
\textbf{Custo Total} & & & \textbf{R\$ 128,73} \\ \bottomrule
\end{tabular}
\end{table}

A partir do levantamento dos insumos detalhados na tabela acima, o custo total para a montagem do protótipo resultou em R\$ 128,73. Esse valor engloba tanto a parte eletrônica principal quanto a estrutura física e os itens de fixação. A carcaça e a placa STM32 representaram as maiores parcelas do orçamento, confirmando a viabilidade financeira do projeto.

% ==============================================================================
% 7. LIMITAÇÕES E TRABALHOS FUTUROS
% ==============================================================================
\section{Limitações e Trabalhos Futuros}

\subsection{Limitações do Projeto}
\hspace*{1.25cm}Embora o protótipo do Stream Deck tenha atingido satisfatoriamente os objetivos propostos de controle e envio confiável de atalhos em tempo real, a versão atual do sistema apresenta limitações técnicas decorrentes do cronograma acadêmico e restrições materiais:

\begin{enumerate}
    \item \textbf{Montagem por Fiação Aérea:} Apesar de o layout da PCB ter sido completamente projetado e validado no KiCad em camada única (Face Simples \texttt{B.Cu}) com trilhas de $0.8\,\text{mm}$ a $1.2\,\text{mm}$, limitações logísticas impediram a corrosão física da placa a tempo para a entrega. A montagem interna recorreu à fiação flexível ponto a ponto para a soldagem dos switches e diodos $1\text{N}4148$.
    \item \textbf{Ausência de Feedback Visual Embarcado:} O hardware opera como um dispositivo puro de entrada USB Custom HID, carecendo de display físico embarcado na carcaça para indicação de perfil ativo, dependendo do monitoramento gerido na tela do computador pela aplicação Python.
    \item \textbf{Dependência da Aplicação Hospedeira:} O microcontrolador envia os códigos genéricos de teclas (F13 a F21), requerendo a presença do serviço Python no computador hospedeiro para mapear os atalhos para ações específicas do sistema.
\end{enumerate}

\subsection{Trabalhos Futuros}
\hspace*{1.25cm}Como diretrizes de engenharia para dar continuidade ao aprimoramento técnico do dispositivo, são propostos os seguintes trabalhos futuros:

\begin{enumerate}
    \item \textbf{Fabricação Física da PCB KiCad:} Proceder com a fabricação física do layout desenvolvido nas Figuras 2 e 3 por meio de corrosão artesanal (transferência térmica e Percloreto de Ferro), eliminando a fiação aérea.
    \item \textbf{Integração de Display OLED:} Incorporar um display gráfico compacto (OLED SSD1306 via barramento I2C) na tampa da carcaça 3D para exibição dinâmica de perfis e nomes de macros atribuídos às teclas.
    \item \textbf{Armazenamento Autônomo Local:} Desenvolver rotinas no firmware para gravação dinâmica em memória Flash interna ou chip de memória EEPROM externo via I2C/SPI, permitindo a portabilidade autônoma \textit{plug-and-play} em qualquer computador.
\end{enumerate}

% ==============================================================================
% 8. CONCLUSÃO
% ==============================================================================
\section{Conclusão}
\hspace*{1.25cm}O desenvolvimento do Stream Deck customizado demonstrou-se totalmente viável na integração entre a arquitetura de hardware e o projeto mecânico. A utilização do microcontrolador STM32F103C8T6 (Blue Pill), configurado via STM32CubeMX e programado com \textbf{Interrupção de Timer de Hardware (TIM2 a 100 Hz)} para operar como um dispositivo USB HID com clock ajustado em 48 MHz, assegurou a comunicação nativa e o disparo imediato de atalhos e macros no computador sem o uso de \textit{polling}. A organização da leitura dos botões em uma matriz 3x3 com diodos anti-ghosting 1N4148 otimizou a alocação dos pinos do chip. A PCB projetada em \textbf{face simples (\texttt{B.Cu}) com trilhas reforçadas de $0.8\,\text{mm}$ a $1.2\,\text{mm}$} viabilizou a confecção artesanal. Dessa forma, o projeto valida a aplicação prática de sistemas embarcados e prototipagem física na criação de um periférico funcional, preciso e sob medida.

\end{document}

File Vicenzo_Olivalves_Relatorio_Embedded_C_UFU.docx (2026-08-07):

UNIVERSIDADE FEDERAL DE UBERLÂNDIA
FACULDADE DE ENGENHARIA ELÉTRICA — FEELT
DISCIPLINA DE SISTEMAS EMBARCADOS I

RELATÓRIO TÉCNICO E GUIA COMPLETO DE ESTUDO
EMBEDDED C (VÍDEOS 1 E 2)

Discente: Vicenzo De Marco Olivalves Matrícula: 12421ECP006 Curso: Engenharia de Computação | Docente Responsável: Prof. Jeovane Vicente de Sousa Semestre: 2026/1

1. Acompanhamento Detalhado do Vídeo 1: Embedded C - Parte 1/2

No primeiro vídeo, o professor Marcelo começa explicando o porquê aprender C para sistemas embarcados exige mudar a forma de pensar dos programadores, apresentando a diferença essencial entre escrever um programa em C de forma tradicional no computador e escrever um programa em C em um microcontrolador, como no caso de uma placa STM32F103 Blue Pill. No caso dessas diferenças, é que no desktop o programa roda em cima de um sistema operacional, como Windows, Linux e afins. A linguagem C é usada para criar aplicativos de alto nível. O sistema operacional aloca a memória RAM virtualizada para o seu programa, isola o processo e gerencia os arquivos. Se o programa tentar acessar um endereço de memória que não é dele, o sistema operacional intervém e dispara um erro de segmentação.

Agora no caso de um sistema embarcado, o código roda direto na placa, então não tem essa rede de proteção, pois não tem a presença de um sistema operacional. O programador tem total controle e responsabilidade sobre o hardware e afins. É o programador que configura o clock, barramentos, direção de pinos de saída e entrada (GPIO), interrupções e afins, igual estamos fazendo na matéria.

Junto dessa ideia de rodar o código diretamente no hardware sem um sistema operacional por cima, a aula avança para a estrutura do fluxo de execução na função main. Em um código C comum, a função "int main(void)" é chamada pelo sistema operacional, executa uma sequência e volta retornando 0 e a CPU volta a outras funções. No caso de um microcontrolador embarcado, a função main() não me pode chegar ao fim, pois se chegar a CPU entra em um estado indefinido, o ponteiro cai para um endereço inválido e o sistema trava ou reinicia. Por conta disso a arquitetura do firmware tem duas etapas obrigatórias:

• Setup: Roda apenas uma vez quando a placa é ligada ou resetada e é onde configuramos o clock, inicializamos os pinos de GPIO como entrada ou saída e ligamos os periféricos.

• Loop: Como resposta àquela ideia de que não pode sair da main, após o código inicializar, ele fica em um laço de while(1), aí o processador fica executando tarefas continuamente ou entra em modo de repouso esperando por uma interrupção.

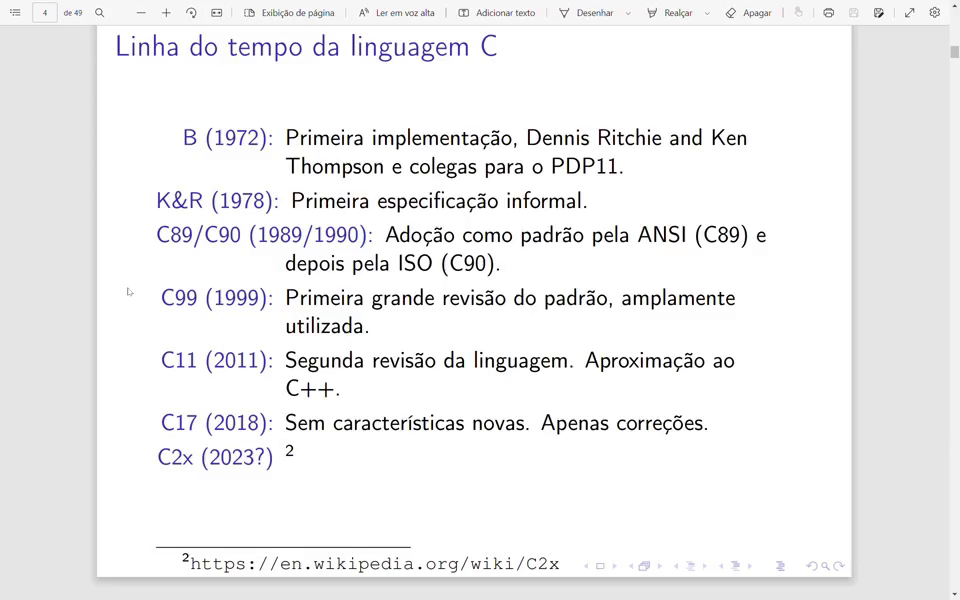
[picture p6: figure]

Figura 1: Slide do minuto 03:59 apresentando a linha do tempo e a evolução histórica dos padrões da linguagem C.

1.1 Ponto Flutuante (float / double) vs. Aritmética de Ponto Fixo (Sem FPU)

Logo no início do vídeo, o professor faz um comentário crucial sobre o uso de Ponto Flutuante (float e double) em microcontroladores. Ele explica que microcontroladores mais simples ou de custo reduzido (como o ARM Cortex-M3 do STM32F103) **não possuem uma FPU de hardware (Floating Point Unit)**. Quando o programador escreve operações matematicas usando float ou double no C, o compilador é forçado a incluir uma biblioteca de software (Soft-Float) gigantesca dentro da memória Flash ROM para emular as operações em ponto flutuante por instrução de software. Isso resulta em um consumo enorme de memória Flash e faz com que uma simples multiplicação leve dezenas de ciclos de clock extras de CPU. Por isso, a norma de Embedded C (ISO/IEC TR 18037) preconiza o uso de Aritmética de Ponto Fixo (Fixed-Point Arithmetic) ou o uso de inteiros escalonados (ex.: medir milivolt em vez de volt como float) para garantir máxima velocidade e economia de código.

1.2 Histórico dos Padrões C e a Revolução do C99 para Embarcados

Na sequência do vídeo, o professor navega pelo slide de linha do tempo do C (B 1972, K&R 1978, C89/C90, C99, C11, C17). O professor destaca que a revisão C99 (1999) é a mais marcante para sistemas embarcados. Foi nela que surgiu a biblioteca <stdint.h> com os inteiros de largura fixa (uint8_t, uint16_t, uint32_t), além de comentários de linha dupla (//) e inicializações no meio do bloco.

1.3 Esclarecimento: Existe uma linguagem 'Embedded C'?

O professor faz uma observação importante sobre o termo 'Embedded C': tecnicamente, não existe uma linguagem nova ou um compilador separado. O termo se refere à extensão ISO/IEC TR 18037 que padronizou o suporte do C para aritmética de ponto fixo, gerenciamento de espaços nomeados de memória e acesso direto aos registradores de hardware.

1.4 Tabela de Palavras Reservadas (Keywords)

A aula apresenta a tabela com as 32 palavras reservadas da linguagem C (auto, break, case, char, const, continue, default, do, double, else, enum, extern, float, for, goto, if, inline, int, long, register, restrict, return, short, signed, sizeof, static, struct, switch, typedef, union, unsigned, void, volatile, while). O professor comenta rapidamente que no C11 foram adicionadas palavras especiais como _Alignas, _Atomic, _Generic, _Noreturn e _Static_assert.

1.5 Organização de Arquivos e Cabeçalhos (APIs e Include Guards)

O professor explica que um arquivo de inclusão (.h) deve ser projetado como uma API, expondo apenas protótipos de funções públicas. Para evitar inclusão duplicada, ensina-se a usar as travas do pré-processador (#ifndef DEMO_H_ #define DEMO_H_ ... #endif). Ele comenta rapidamente também sobre o bloco extern "C", que previne a decoração de nomes (Name Mangling) quando o código C é vinculado a projetos em C++.

1.6 O Especificador extern

O professor explica que a palavra-chave extern é usada para avisar ao compilador que uma variável global ou função citada naquele arquivo está declarada e alocada fisicamente em outro arquivo .c do projeto.

1.7 Mapeamento de Memória (Flash ROM, SRAM e Seções do Linker Script)

A aula detalha como o compilador distribui o programa na memória física do STM32 através do arquivo de linkagem (.ld):

• Seção .text (Flash ROM - 0x08000000): Armazena permanentemente o binário compilado e as variáveis const. Não apaga ao desligar a placa.

• Seção .data (SRAM - 0x20000000): Guarda as variáveis globais e estáticas inicializadas. O boot copia os valores da Flash para a RAM.

• Seção .bss (SRAM - 0x20000000): Guarda as variáveis globais não inicializadas. O boot zera toda essa área.

• Pilha (Stack): Área usada para alocar variáveis locais e registradores temporários de funções. O professor faz um alerta rigoroso sobre o perigo de estouro da pilha (Stack Overflow) se abusarmos de vetores locais grandes ou chamadas de funções recursivas.

• Monte (Heap): Usada para alocação dinâmica (malloc). O professor comenta que no desenvolvimento Bare-Metal o uso de malloc é desaconselhado por causar fragmentação imprevisível.

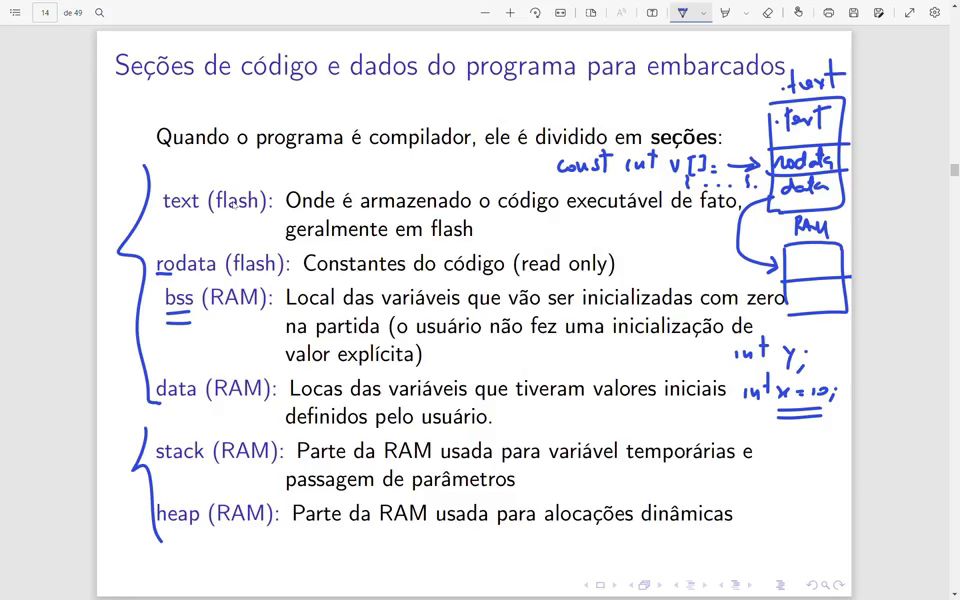
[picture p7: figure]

Figura 2: Slide do minuto 61:59 detalhando as seções de memória (.text, .data, .bss) e o arquivo de linkagem (.ld).

1.8 Especificadores de Armazenamento: volatile, const, static, auto e register

O professor dá um foco enorme para a palavra-chave volatile. Ela avisa ao compilador que a variável pode mudar a qualquer momento por hardware externo ou interrupção (ISR), desativando otimizações que travariam o valor nos registradores da CPU (R0..R12).

O qualificador const força o armazenamento de tabelas na Flash ROM. O static preserva o valor de variáveis locais entre chamadas de função e restringe a visibilidade de variáveis globais apenas ao próprio arquivo .c. O professor comenta rapidamente sobre o especificador register (que solicita salvar a variável direto nos registradores internos da CPU) e auto (escopo padrão local).

1.9 Manipulação de Registradores com Bitwise

Na etapa final do vídeo 1, o professor demonstra como alterar bits individuais em registradores de 32 bits através de operações bitwise sem destruir as configurações dos outros pinos: usa-se OR (|) para SET (ligar pino), AND com NOT (& ~) para CLEAR (desligar pino), XOR (^) para TOGGLE (inverter pino), e MASK com AND (&) para testar se um pino de entrada está em nível alto.

2. Acompanhamento Detalhado do Vídeo 2: Embedded C - Parte 2/2

2.1 Passagem por Valor vs. Passagem por Referência

O segundo vídeo começa analisando a passagem de parâmetros em funções: na passagem por valor, os dados são copiados para a pilha (Stack); na passagem por referência, a função recebe o ponteiro do dado, economizando memória na pilha e permitindo alterar a variável original.

2.2 Ponteiros, Arrays e Aritmética de Ponteiros

O professor explica que em C, o nome de um vetor é um ponteiro constante para o seu primeiro elemento. Ao somar +1 a um ponteiro, a CPU avança o tamanho exato em bytes do tipo de dado apontado. Ele cita rapidamente o tipo uintptr_t da <stdint.h>, usado para converter ponteiros em números inteiros do tamanho da palavra da arquitetura sem gerar alertas do compilador.

2.3 Ponteiros para Função, Tabela IVT e Callbacks da HAL

O professor explica que o nome de qualquer função é um ponteiro para o seu endereço de início na Flash. Ele conecta isso diretamente com a Tabela de Vetores de Interrupção (IVT alocada em 0x08000000): quando ocorre uma interrupção de hardware (como o estouro do Timer TIM2), a CPU lê o ponteiro da tabela e salta direto para a função ISR de callback (ex.: HAL_TIM_PeriodElapsedCallback).

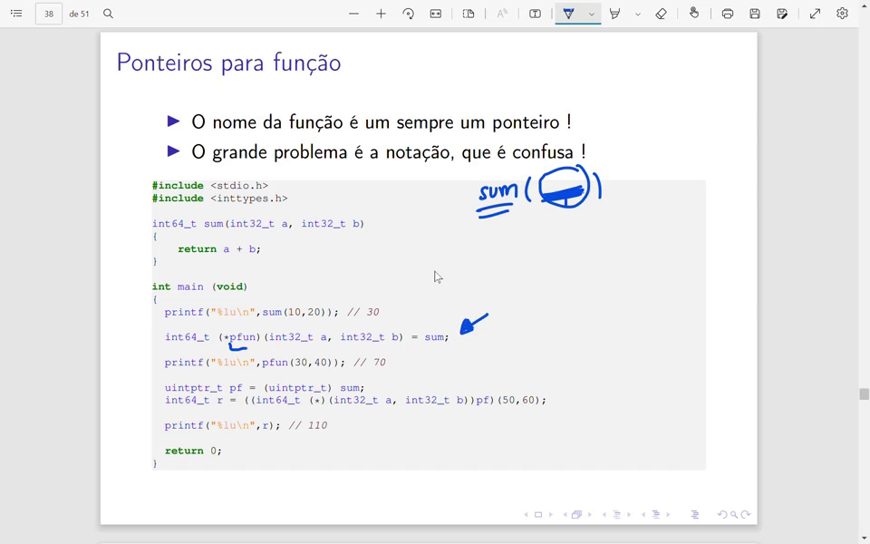
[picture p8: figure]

Figura 3: Slide do minuto 38:59 apresentando a sintaxe e a aplicação de Ponteiros para Função.

2.4 Demonstração Prática no Godbolt Compiler Explorer

No minuto 62:59 do vídeo 2, o professor abre ao vivo o site Godbolt Compiler Explorer (godbolt.org) com o compilador ARM GCC 11.2 (none). Ele digita códigos C com volatile e const para mostrar no lado direito o código Assembly ARM gerado (instruções LDR/STR), demonstrando na prática como o compilador obedece a essas instruções.

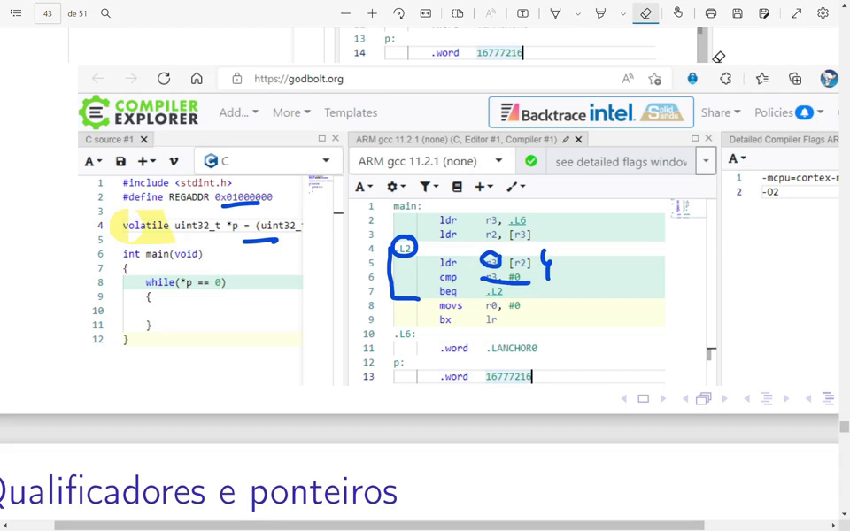
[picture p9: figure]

Figura 4: Demonstração ao vivo no Godbolt Compiler Explorer (minuto 62:59) analisando as instruções Assembly geradas pelo ARM GCC.

2.5 Qualificadores em Ponteiros de Leitura (const uint8_t *buf)

O professor recomenda a boa prática de declarar ponteiros de leitura de buffers com const (ex.: const uint8_t *buf em drivers spi_write ou lcd_write), garantindo que a função não altere o conteúdo original dos dados.

2.6 Mapeamento de Registradores com struct (Memory-Mapped I/O)

O mapa de memória do ARM Cortex-M coloca os registradores de um periférico (como a porta GPIOA) em posições contíguas sequenciais (offsets 0x00, 0x04, 0x08, 0x0C). Ao criar uma struct que espelha essa sequência, podemos apontar um ponteiro para o endereço base da porta (0x40010800) e acessar os pinos com a sintaxe GPIOA->ODR, exatamente como é feito nas bibliotecas ST HAL e CMSIS.

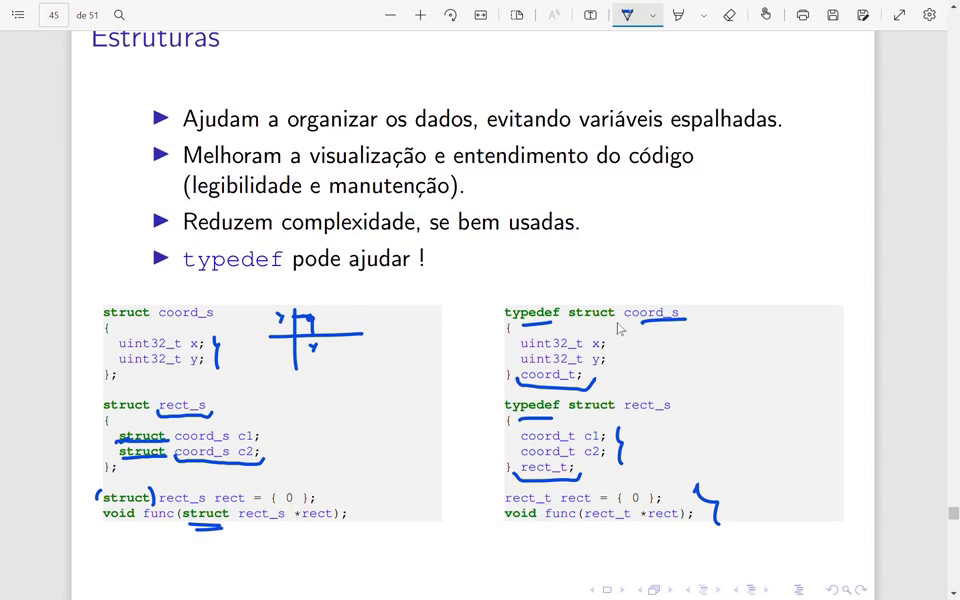
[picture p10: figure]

Figura 5: Slide do minuto 70:59 demonstrando a organização de dados e periféricos através de estruturas (struct).

2.7 Compartilhamento de Memória RAM com union

Diferente da struct, na union todos os membros compartilham a mesma posição física na memória RAM. O professor mostra que isso é muito útil para fatiar um dado numérico de 32 bits (uint32_t) em 4 bytes separados (uint8_t) para envio por pacotes USB HID ou comunicação serial UART sem precisar de máscaras manuais de bitwise.

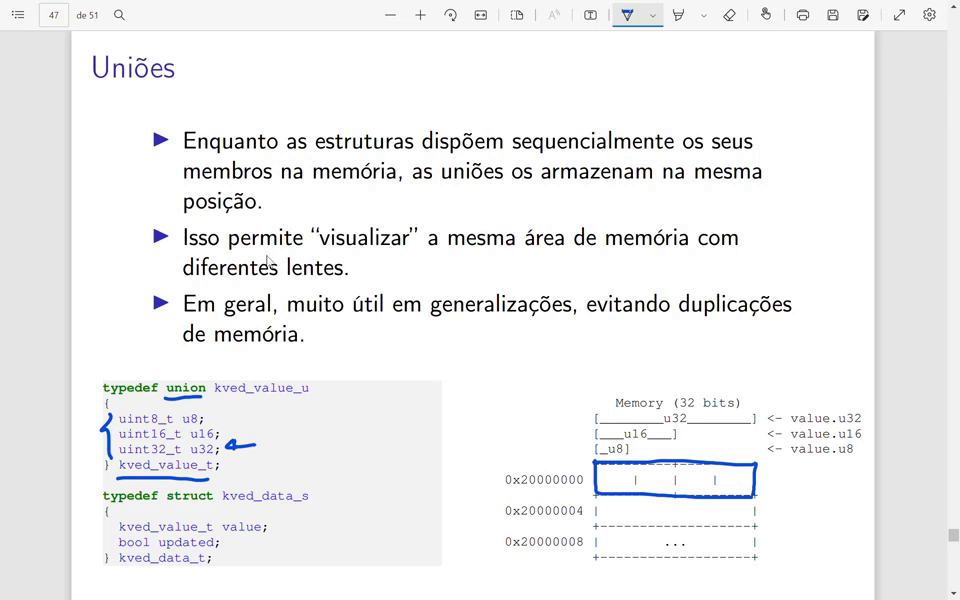
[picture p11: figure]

Figura 6: Slide do minuto 78:59 explicando o funcionamento de Unióes (union) e o compartilhamento de RAM.

2.8 Máquinas de Estados Finitos (FSM) com enum

Substituir números inteiros soltos por nomes de estados legíveis (enum) permite construir Máquinas de Estados Finitos (FSM) conectadas a laços switch-case, aumentando a segurança do código e evitando que o sistema caia em estados inválidos.

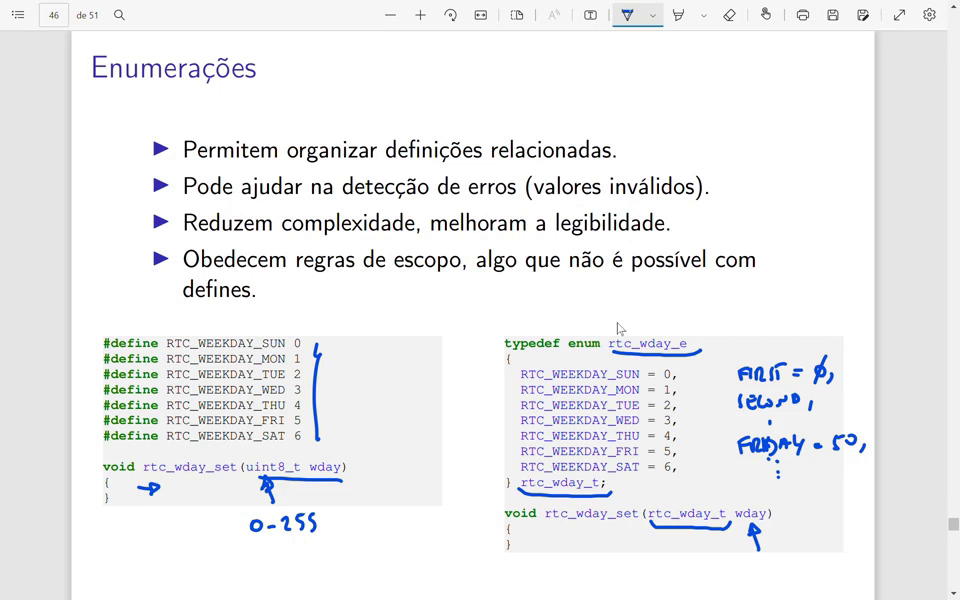
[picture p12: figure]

Figura 7: Slide do minuto 74:59 demonstrando a organização de enumerações (enum) para controle de fluxo.

2.9 Exemplo Completo de Objeto Polimórfico (obj_t)

O professor apresenta um exemplo avançado reunindo struct, union e enum (obj_t) para processar diferentes tipos de dados e formatos geométricos no mesmo buffer de memória sem desperdiçar RAM.

2.10 Organização do Modelo de Código-Fonte do Projeto

A aula se encerra exibindo a estrutura de organização dos arquivos de um projeto C profissional: separação entre cabeçalhos de inclusão de linguagem, inclusões de projetos, macros #define, protótipos de função e variáveis externas.

3. Conclusão e Síntese Comparativa

Abaixo apresento a tabela resumo comparando as principais diferenças observadas entre a programação em C para computadores e para sistemas embarcados:

Critério Técnico | C para PC (Desktop) | Embedded C (Embarcados)
Ambiente de Execução | Aplicativo sobre Sistema Operacional | Firmware Bare-Metal no silício
Acesso ao Hardware | Bloqueado pelo SO / Via Syscalls | Direto por registradores MMIO
Ciclo de Vida (main) | Retorna 0 para o SO ao terminar | Loop infinito while(1) ou repouso __WFI()
Determinismo de Tempo | Não-determinístico (escalonado pelo SO) | Tempo Real determinístico por ISR/NVIC
Qualificador volatile | Raramente necessário | Obrigatório em ISRs e registradores
Tipos de Dados Inteiros | Uso de int de tamanho variável | Obrigatório <stdint.h> (uint8_t, uint32_t)
Gerenciamento de RAM | Abundante com memória virtual | Estrito e contado (SRAM vs Flash ROM)

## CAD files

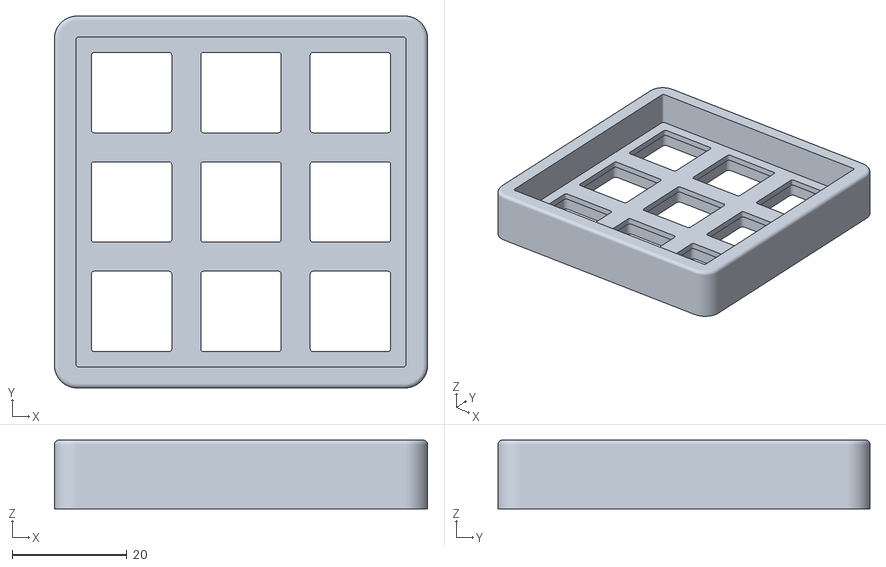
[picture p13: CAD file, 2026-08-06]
3D/obj_4_VOID9 - Bottom - Angled - Short - oben.step.stl
65.0 x 64.8 x 12.0

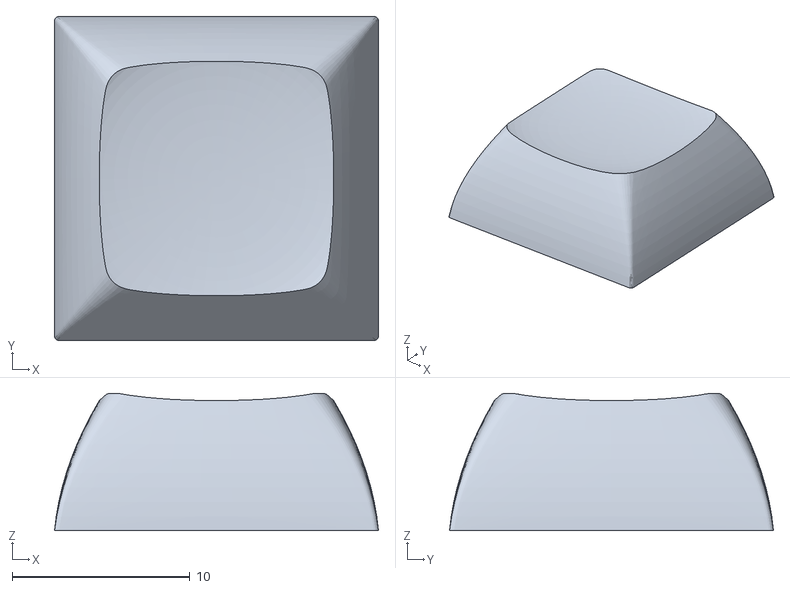
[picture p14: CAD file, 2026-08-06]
3D/obj_3_16 dsa 3.stl
18.2 x 18.2 x 7.74

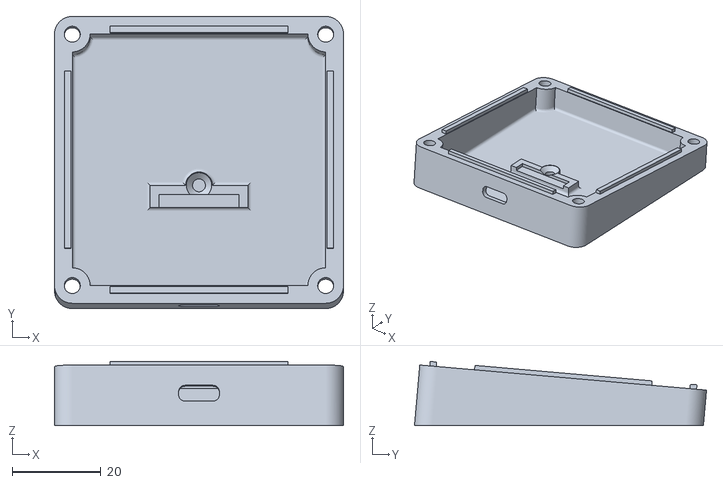
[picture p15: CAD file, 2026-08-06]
3D/obj_2_VOID9 - Bottom - Angled - Short - unten.step.stl
65.0 x 65.7 x 14.4

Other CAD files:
3D/obj_1_16 dsa 3.stl
3D/obj_6_16 dsa 3.stl
3D/obj_7_16 dsa 3.stl
3D/obj_11_16 dsa 3.stl
3D/obj_8_16 dsa 3.stl
3D/obj_9_16 dsa 3.stl
3D/obj_10_16 dsa 3.stl
3D/obj_5_16 dsa 3.stl

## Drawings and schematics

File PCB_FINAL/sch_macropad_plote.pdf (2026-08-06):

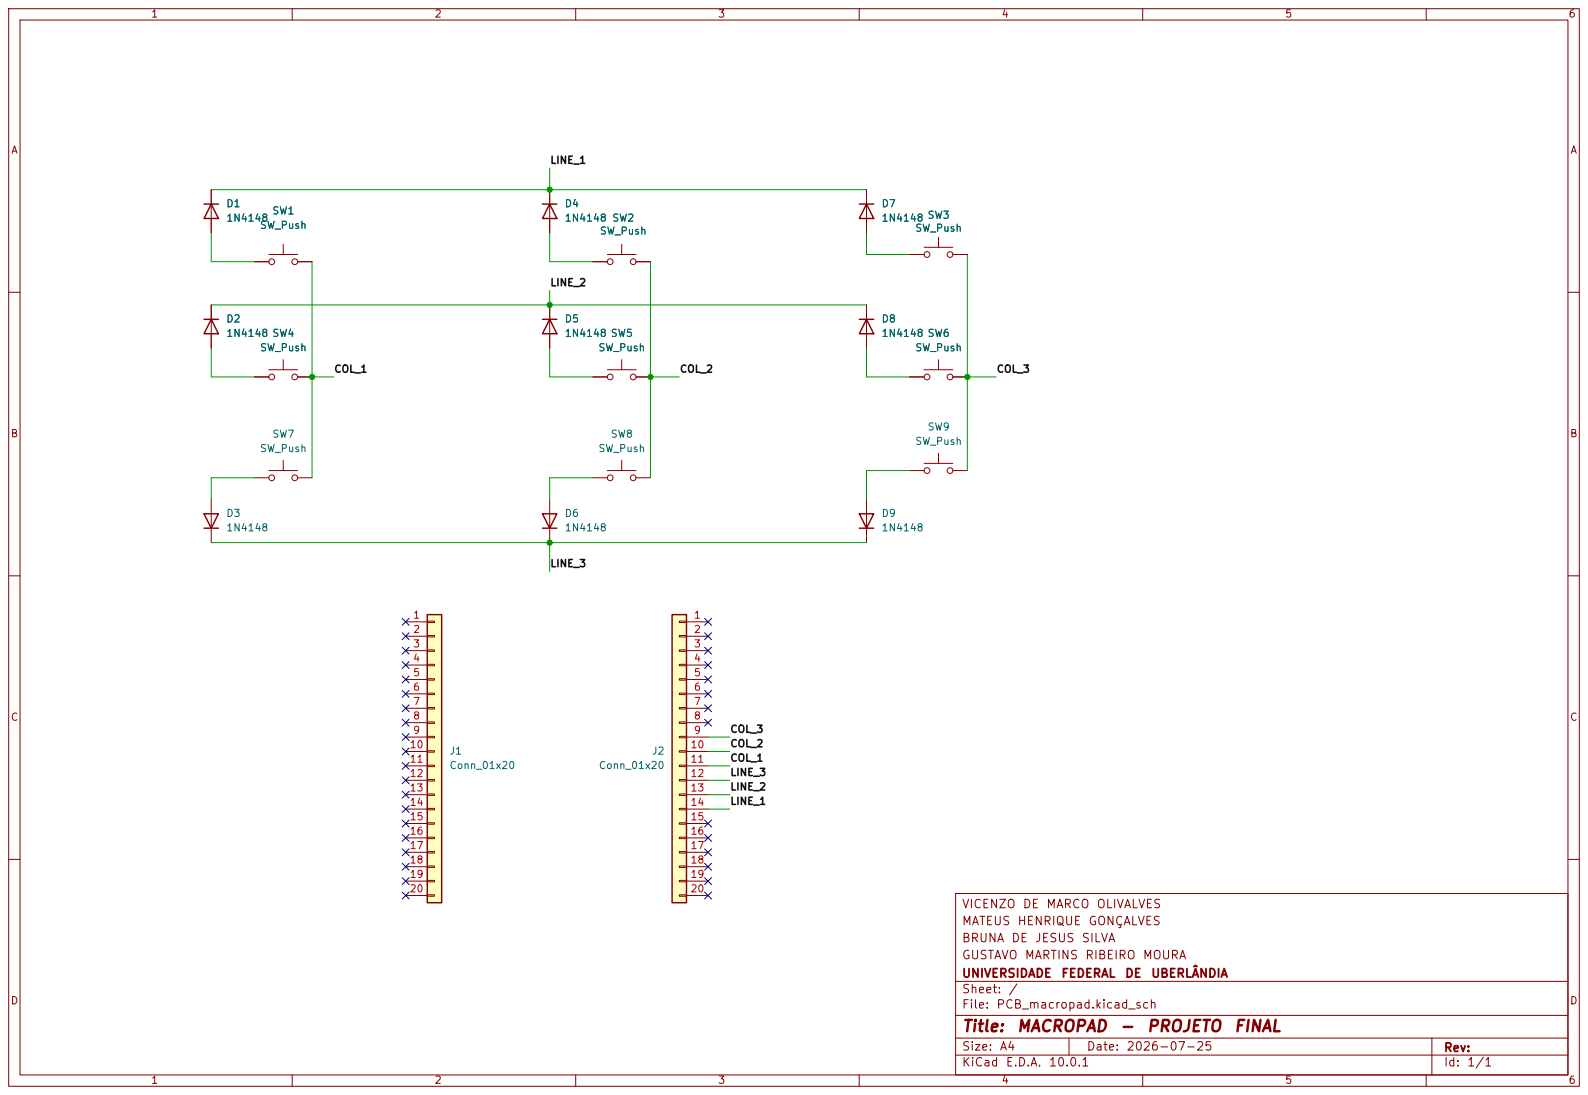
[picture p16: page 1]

VICENZO DE MARCO OLIVALVES
MATEUS HENRIQUE GONÇALVES
BRUNA DE JESUS SILVA
GUSTAVO MARTINS RIBEIRO MOURA
UNIVERSIDADE FEDERAL DE UBERLÂNDIA
Sheet: /
File: PCB_macropad.kicad_sch
Title: MACROPAD - PROJETO FINAL

Size: A4 | Rev:
KiCad E.D.A. 10.0.1 | Id: 1/1

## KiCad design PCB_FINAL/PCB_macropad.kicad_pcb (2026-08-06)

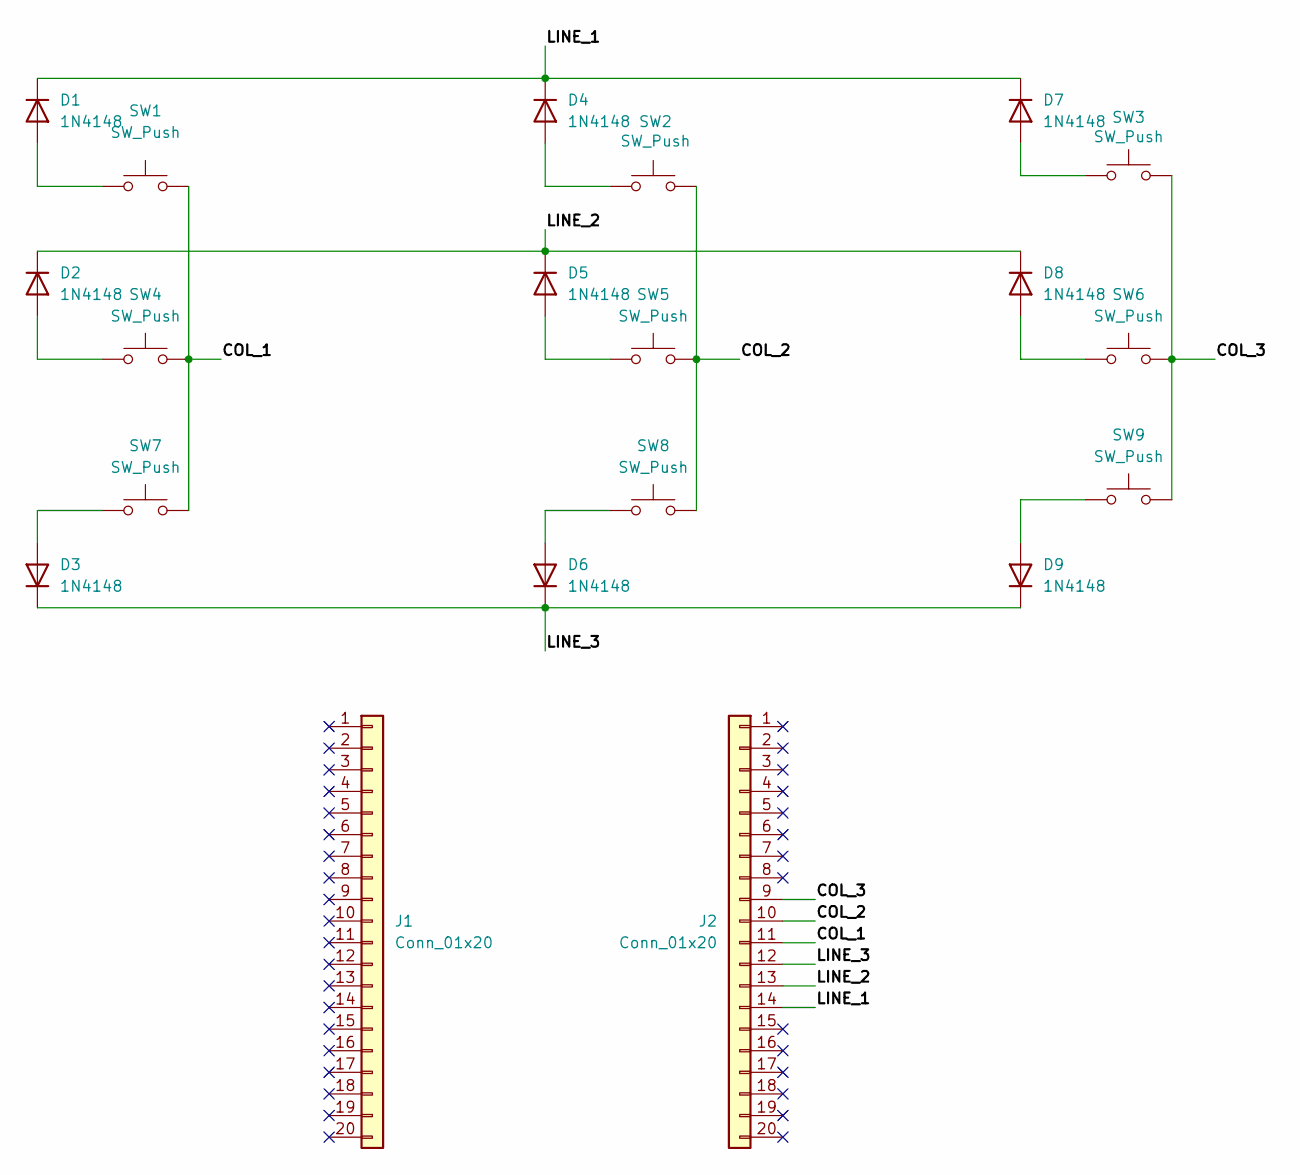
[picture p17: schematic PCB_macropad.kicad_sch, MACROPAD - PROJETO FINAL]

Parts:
D1, D2, D3, D4, D5, D6, D7, D8, D9: 1N4148; D_DO-35_SOD27_P7.62mm_Horizontal
J1, J2: Conn_01x20; PinHeader_1x20_P2.54mm_Vertical
SW1, SW2, SW3, SW4, SW5, SW6, SW7, SW8, SW9: SW_Push; SW_Cherry_MX_1.00u_PCB

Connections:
/COL_1: J2.11, SW1.2, SW4.2, SW7.2
/COL_2: J2.10, SW2.2, SW5.2, SW8.2
/COL_3: J2.9, SW3.2, SW6.2, SW9.2
/LINE_1: D1.1 (K), D4.1 (K), D7.1 (K), J2.14
/LINE_2: D2.1 (K), D5.1 (K), D8.1 (K), J2.13
/LINE_3: D3.1 (K), D6.1 (K), D9.1 (K), J2.12
unnamed: D1.2 (A), SW1.1
unnamed: D2.2 (A), SW4.1
unnamed: D3.2 (A), SW7.1
unnamed: D4.2 (A), SW2.1
unnamed: D5.2 (A), SW5.1
unnamed: D6.2 (A), SW8.1
unnamed: D7.2 (A), SW3.1
unnamed: D8.2 (A), SW6.1
unnamed: D9.2 (A), SW9.1

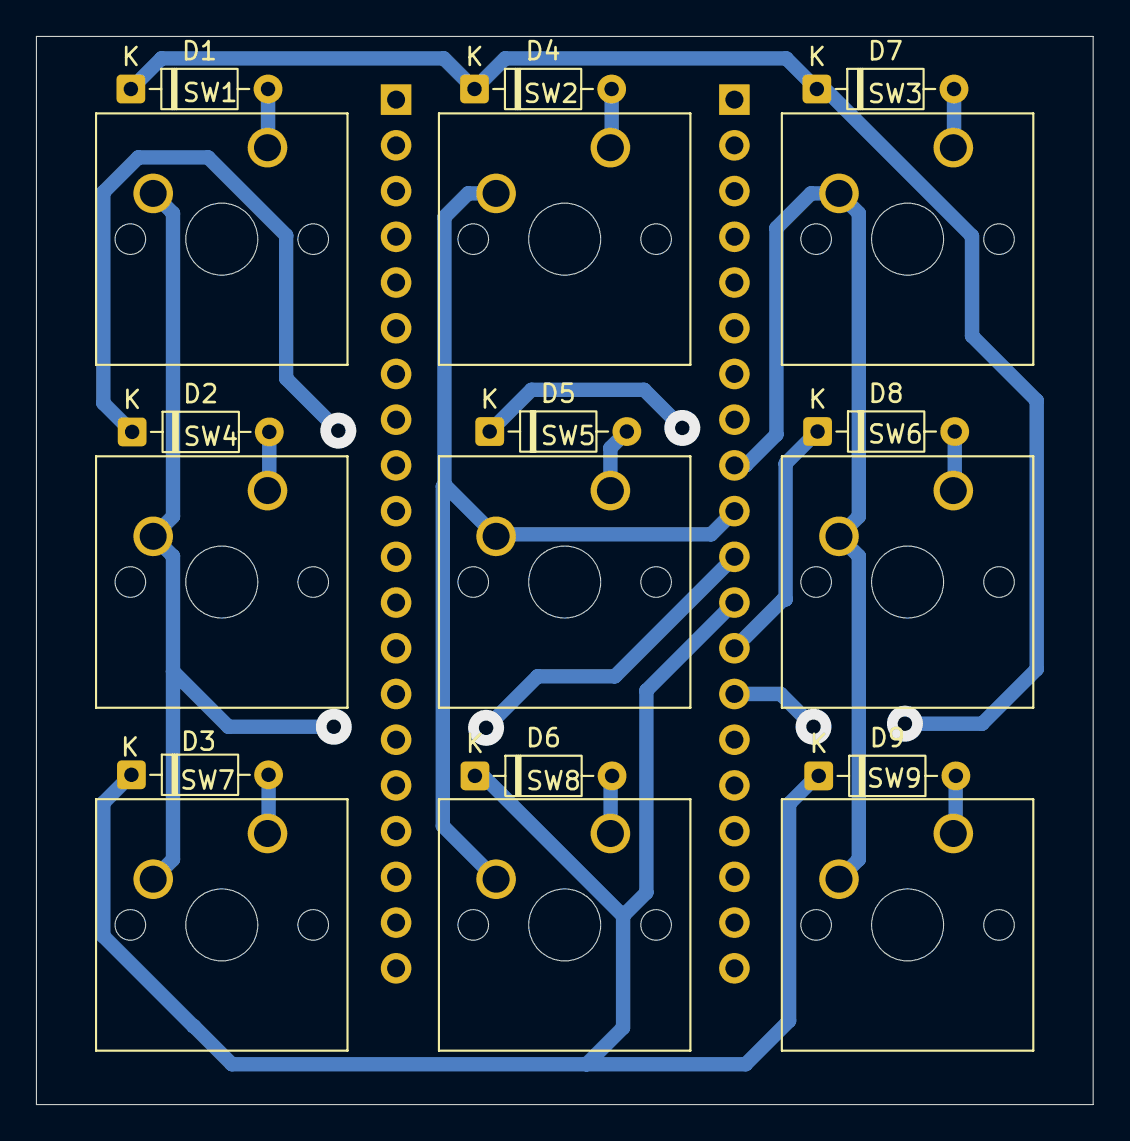
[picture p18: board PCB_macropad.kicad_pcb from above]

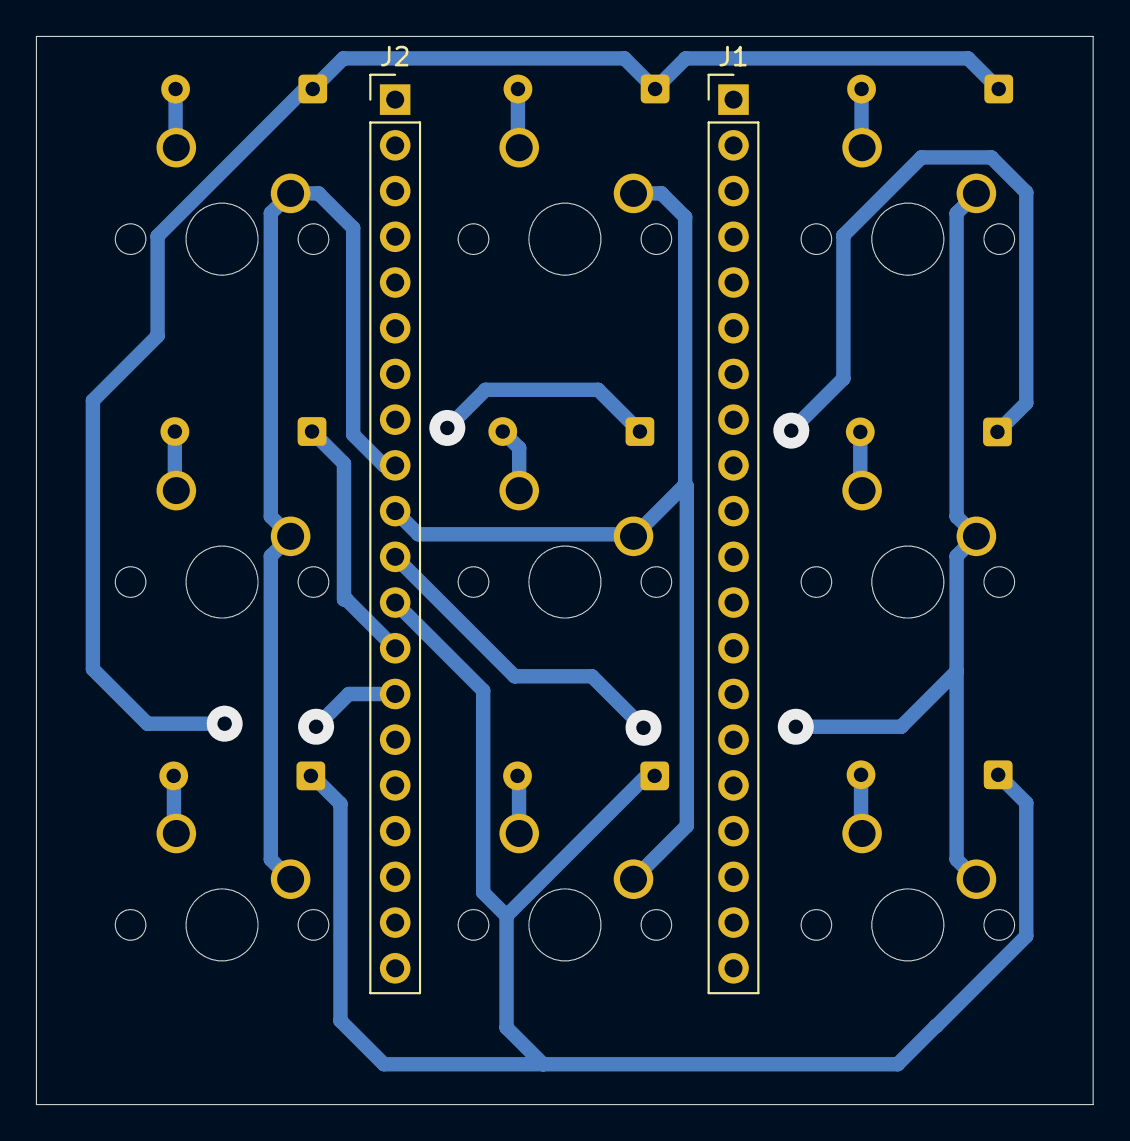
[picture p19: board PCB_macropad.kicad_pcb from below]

Board: 2 copper layers, 58.7 x 59.3 mm, 20 parts (2 on the bottom side), 15 nets.

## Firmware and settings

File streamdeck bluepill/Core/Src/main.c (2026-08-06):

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
/* Includes ------------------------------------------------------------------*/
#include "main.h"
#include "usb_device.h"

/* USER CODE BEGIN Includes */
#include "usbd_customhid.h"
/* USER CODE END Includes */

/* USER CODE BEGIN PTD */
/**
 * @brief Estrutura de dados para controle da Matriz e Debouncing não-bloqueante por ISR.
 */
typedef struct {
    volatile int last_raw_key;     /*!< Última tecla detectada na varredura física (-1 a 8) */
    volatile int stable_valid_key; /*!< Tecla confirmada após a janela de debouncing */
    volatile uint32_t sample_ticks;/*!< Contador de amostras em ms ativado via Timer ISR */
} StreamDeck_State_t;
/* USER CODE END PTD */

/* USER CODE BEGIN PD */
#define DEBOUNCE_THRESHOLD_MS 40   /*!< Janela de estabilização do ruído mecânico em ms */
#define SCAN_TIMER_PERIOD_MS  10   /*!< Período de interrupção do Timer TIM2 (100 Hz) */
#define USB_HID_SCANCODE_F13  0x68 /*!< Código Hexadecimal da tecla F13 no padrão USB HID */
/* USER CODE END PD */

TIM_HandleTypeDef htim2;

/* USER CODE BEGIN PV */
extern USBD_HandleTypeDef hUsbDeviceFS;

/** @brief Mapeamento físico dos pinos das Linhas (PA1, PA2, PA3 - Open Drain Out) */
static uint16_t rowPins[3] = {GPIO_PIN_1, GPIO_PIN_2, GPIO_PIN_3};
static GPIO_TypeDef* rowPorts[3] = {GPIOA, GPIOA, GPIOA};

/** @brief Mapeamento físico dos pinos das Colunas (PA4, PA5, PA6 - Input PullUp) */
static uint16_t colPins[3] = {GPIO_PIN_4, GPIO_PIN_5, GPIO_PIN_6};
static GPIO_TypeDef* colPorts[3] = {GPIOA, GPIOA, GPIOA};

/** @brief Instância global da máquina de estados do Stream Deck */
static volatile StreamDeck_State_t deck_state = {
    .last_raw_key = -1,
    .stable_valid_key = -1,
    .sample_ticks = 0
};
/* USER CODE END PV */

void SystemClock_Config(void);
static void MX_GPIO_Init(void);
static void MX_TIM2_Init(void);
/* USER CODE BEGIN PFP */
int scanMatrix_ISR(void);
void enviarReportUSB(int tecla_id);
void processDebounce_ISR(void);
/* USER CODE END PFP */

/* USER CODE BEGIN 0 */

/**
  * @brief  Varre a matriz de teclas 3x3.
  * @note   Função otimizada executada dentro do contexto de Interrupção por Hardware (Timer ISR).
  * @retval ID da tecla acionada (0 a 8) ou -1 se nenhuma tecla estiver pressionada.
  */
int scanMatrix_ISR(void) {
    for (int r = 0; r < 3; r++) {
        // Coloca a linha atual em nível LÓGICO BAIXO (0V / RESET)
        HAL_GPIO_WritePin(rowPorts[r], rowPins[r], GPIO_PIN_RESET);

        // Estabilização de sinal para capacitância das trilhas da PCB
        for (volatile int i = 0; i < 50; i++) { __NOP(); }

        for (int c = 0; c < 3; c++) {
            // Se a coluna ler 0V, o switch daquela interseção (r, c) foi fechado
            if (HAL_GPIO_ReadPin(colPorts[c], colPins[c]) == GPIO_PIN_RESET) {
                // Restaura a linha para Alta Impedância (SET / Open-Drain Hi-Z)
                HAL_GPIO_WritePin(rowPorts[r], rowPins[r], GPIO_PIN_SET);
                return (r * 3) + c; // Retorna o índice de 0 a 8
            }
        }
        // Restaura a linha para Alta Impedância antes de testar a próxima
        HAL_GPIO_WritePin(rowPorts[r], rowPins[r], GPIO_PIN_SET);
    }
    return -1; // Nenhuma tecla pressionada
}

/**
  * @brief  Constrói e envia o pacote de 8 Bytes USB HID para o computador host.
  * @param  tecla_id ID da tecla (0 a 8) ou -1 para liberada (Release).
  * @retval None
  */
void enviarReportUSB(int tecla_id) {
    uint8_t hid_report[8] = {0}; // Array de 8 bytes no padrão USB HID Keyboard Report

    if (tecla_id != -1) {
        // Byte 0: Teclas modificadoras (Ctrl, Shift, Alt, GUI) -> 0x00
        // Byte 1: Reservado -> 0x00
        // Byte 2: Scancode da tecla primária -> F13 (0x68) + ID
        hid_report[2] = USB_HID_SCANCODE_F13 + tecla_id;
    }

    // Envia o relatório de 8 bytes via EndPoint EP1 IN (Interrupt Transmission)
    USBD_CUSTOM_HID_SendReport(&hUsbDeviceFS, hid_report, sizeof(hid_report));
}

/**
  * @brief  Filtro de Debouncing executado periodicamente a cada estouro do Timer TIM2.
  * @note   Substitui totalmente o Polling. Garante imunidade a ruídos sem bloquear a CPU.
  * @retval None
  */
void processDebounce_ISR(void) {
    int current_key = scanMatrix_ISR();

    if (current_key != deck_state.last_raw_key) {
        deck_state.sample_ticks = HAL_GetTick();
        deck_state.last_raw_key = current_key;
    }

    // Se o sinal se manteve estável durante a janela de 40ms
    if ((HAL_GetTick() - deck_state.sample_ticks) >= DEBOUNCE_THRESHOLD_MS) {
        if (current_key != deck_state.stable_valid_key) {
            deck_state.stable_valid_key = current_key;
            enviarReportUSB(deck_state.stable_valid_key);
        }
    }
}

/**
  * @brief  Callback de Interrupção por Estouro do Timer (TIM2 ISR).
  * @param  htim Ponteiro para o handle do timer que gerou a interrupção.
  * @retval None
  */
void HAL_TIM_PeriodElapsedCallback(TIM_HandleTypeDef *htim) {
    if (htim->Instance == TIM2) {
        // Processa a varredura e o debouncing em tempo real por interrupção
        processDebounce_ISR();
    }
}

/* USER CODE END 0 */

/**
  * @brief  The application entry point.
  * @retval int
  */
int main(void)
{

  /* MCU Configuration--------------------------------------------------------*/

  /* Reset of all peripherals, Initializes the Flash interface and the Systick. */
  HAL_Init();

  /* Configure the system clock */
  SystemClock_Config();

  /* USER CODE BEGIN SysInit */
  /* Força a Re-enumeração USB no Windows (Reset no D+ / PA12) */
  GPIO_InitTypeDef GPIO_InitStruct_USB = {0};
  __HAL_RCC_GPIOA_CLK_ENABLE();
  GPIO_InitStruct_USB.Pin = GPIO_PIN_12;
  GPIO_InitStruct_USB.Mode = GPIO_MODE_OUTPUT_PP;
  GPIO_InitStruct_USB.Speed = GPIO_SPEED_FREQ_LOW;
  HAL_GPIO_Init(GPIOA, &GPIO_InitStruct_USB);
  HAL_GPIO_WritePin(GPIOA, GPIO_PIN_12, GPIO_PIN_RESET);
  HAL_Delay(100);
  /* USER CODE END SysInit */

  /* Initialize all configured peripherals */
  MX_GPIO_Init();
  MX_USB_DEVICE_Init();
  MX_TIM2_Init();
  /* USER CODE BEGIN 2 */
  /* Habilita o sinal de depuração ST-LINK mesmo quando a CPU entra em repouso (__WFI) */
  HAL_DBGMCU_EnableDBGSleepMode();

  /* Inicia o Timer TIM2 com Interrupção de Hardware ativada (100 Hz / 10ms) */
  HAL_TIM_Base_Start_IT(&htim2);
  /* USER CODE END 2 */

  /* Infinite loop */
  /* USER CODE BEGIN WHILE */
  while (1)
  {
    /* USER CODE END WHILE */

    /* USER CODE BEGIN 3 */
    // __WFI(); // Comentado para permitir leitura ao vivo (Live Expressions) via ST-LINK
  }
  /* USER CODE END 3 */
}

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


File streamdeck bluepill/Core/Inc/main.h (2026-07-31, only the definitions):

#define LINE_1_Pin GPIO_PIN_1
#define LINE_1_GPIO_Port GPIOA
#define LINE_2_Pin GPIO_PIN_2
#define LINE_2_GPIO_Port GPIOA
#define LINE_3_Pin GPIO_PIN_3
#define LINE_3_GPIO_Port GPIOA
#define COL_1_Pin GPIO_PIN_4
#define COL_1_GPIO_Port GPIOA
#define COL_2_Pin GPIO_PIN_5
#define COL_2_GPIO_Port GPIOA
#define COL_3_Pin GPIO_PIN_6
#define COL_3_GPIO_Port GPIOA

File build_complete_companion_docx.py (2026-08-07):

# -*- coding: utf-8 -*-
"""
==============================================================================
 SCRIPT DE GERAÇÃO DO RELATÓRIO EXAUSTIVO COM PONTO FLUTUANTE (.DOCX)
 ATIVIDADE DE EMBEDDED C (VÍDEOS 1 E 2) — UFU / FEELT
==============================================================================
 Discente: Vicenzo De Marco Olivalves (12421ECP006)
 Disciplina: Sistemas Embarcados I — Prof. Jeovane Vicente de Sousa
"""

import os
import docx
from docx.shared import Inches, Pt, RGBColor
from docx.enum.text import WD_ALIGN_PARAGRAPH
from docx.enum.table import WD_TABLE_ALIGNMENT
from docx.oxml import parse_xml
from docx.oxml.ns import nsdecls

def set_cell_background(cell, hex_color):
    tcPr = cell._tc.get_or_add_tcPr()
    shd = parse_xml(f'<w:shd {nsdecls("w")} w:fill="{hex_color}"/>')
    tcPr.append(shd)

def create_exhaustive_word_document_v2():
    doc = docx.Document()

    # Margens (2.5 cm)
    for section in doc.sections:
        section.top_margin = Inches(0.98)
        section.bottom_margin = Inches(0.98)
        section.left_margin = Inches(0.98)
        section.right_margin = Inches(0.98)

    # Cores
    c_primary = RGBColor(35, 38, 121)    # Azul #232679
    c_dark = RGBColor(15, 20, 60)       # Escuro
    c_body = RGBColor(31, 41, 55)       # Texto normal #1f2937

    # TÍTULO E CABEÇALHO
    p_title = doc.add_paragraph()
    p_title.alignment = WD_ALIGN_PARAGRAPH.CENTER
    r_title = p_title.add_run("UNIVERSIDADE FEDERAL DE UBERLÂNDIA\nFACULDADE DE ENGENHARIA ELÉTRICA — FEELT\nDISCIPLINA DE SISTEMAS EMBARCADOS I")
    r_title.bold = True
    r_title.font.name = 'Calibri'
    r_title.font.size = Pt(11)
    r_title.font.color.rgb = c_primary

    p_main_title = doc.add_paragraph()
    p_main_title.alignment = WD_ALIGN_PARAGRAPH.CENTER
    p_main_title.paragraph_format.space_before = Pt(16)
    p_main_title.paragraph_format.space_after = Pt(12)
    r_main = p_main_title.add_run("RELATÓRIO TÉCNICO E GUIA COMPLETO DE ESTUDO\nEMBEDDED C (VÍDEOS 1 E 2)")
    r_main.bold = True
    r_main.font.name = 'Calibri'
    r_main.font.size = Pt(15)
    r_main.font.color.rgb = c_primary

    # IDENTIFICAÇÃO DO ALUNO E PROFESSOR
    table_meta = doc.add_table(rows=1, cols=2)
    table_meta.alignment = WD_TABLE_ALIGNMENT.CENTER
    cell_l, cell_r = table_meta.rows[0].cells
    cell_l.width = Inches(3.2)
    cell_r.width = Inches(3.2)

    p_l = cell_l.paragraphs[0]
    p_l.add_run("Discente: ").bold = True
    p_l.add_run("Vicenzo De Marco Olivalves\n")
    p_l.add_run("Matrícula: ").bold = True
    p_l.add_run("12421ECP006\n")
    p_l.add_run("Curso: ").bold = True
    p_l.add_run("Engenharia de Computação")
    for r in p_l.runs:
        r.font.name = 'Calibri'
        r.font.size = Pt(10)

    p_r = cell_r.paragraphs[0]
    p_r.alignment = WD_ALIGN_PARAGRAPH.RIGHT
    p_r.add_run("Docente Responsável:\n").bold = True
    p_r.add_run("Prof. Jeovane Vicente de Sousa\n")
    p_r.add_run("Semestre: ").bold = True
    p_r.add_run("2026/1")
    for r in p_r.runs:
        r.font.name = 'Calibri'
        r.font.size = Pt(10)

    doc.add_paragraph().paragraph_format.space_after = Pt(10)

    def add_h1(text):
        p = doc.add_paragraph()
        p.paragraph_format.space_before = Pt(14)
        p.paragraph_format.space_after = Pt(6)
        p.paragraph_format.keep_with_next = True
        r = p.add_run(text)
        r.bold = True
        r.font.name = 'Calibri'
        r.font.size = Pt(13)
        r.font.color.rgb = c_primary

    def add_h2(text):
        p = doc.add_paragraph()
        p.paragraph_format.space_before = Pt(10)
        p.paragraph_format.space_after = Pt(4)
        p.paragraph_format.keep_with_next = True
        r = p.add_run(text)
        r.bold = True
        r.font.name = 'Calibri'
        r.font.size = Pt(11)
        r.font.color.rgb = c_dark

    def add_body(text, bold_prefix=None):
        p = doc.add_paragraph()
        p.alignment = WD_ALIGN_PARAGRAPH.JUSTIFY
        p.paragraph_format.space_after = Pt(6)
        p.paragraph_format.line_spacing = 1.15
        if bold_prefix:
            r_pre = p.add_run(bold_prefix)
            r_pre.bold = True
            r_pre.font.name = 'Calibri'
            r_pre.font.size = Pt(11)
            r_pre.font.color.rgb = c_body
        r = p.add_run(text)
        r.font.name = 'Calibri'
        r.font.size = Pt(11)
        r.font.color.rgb = c_body

    def add_figure(img_path, caption_text):
        if os.path.exists(img_path):
            p_img = doc.add_paragraph()
            p_img.alignment = WD_ALIGN_PARAGRAPH.CENTER
            p_img.paragraph_format.space_before = Pt(8)
            p_img.paragraph_format.space_after = Pt(2)
            run = p_img.add_run()
            run.add_picture(img_path, width=Inches(5.0))
            
            p_cap = doc.add_paragraph()
            p_cap.alignment = WD_ALIGN_PARAGRAPH.CENTER
            p_cap.paragraph_format.space_after = Pt(10)
            r_cap = p_cap.add_run(caption_text)
            r_cap.italic = True
            r_cap.font.name = 'Calibri'
            r_cap.font.size = Pt(9.5)
            r_cap.font.color.rgb = RGBColor(100, 100, 100)

    # --------------------------------------------------------------------------
    # VÍDEO 1: CONCEITOS E ARQUITETURA
    # --------------------------------------------------------------------------
    add_h1("1. Acompanhamento Detalhado do Vídeo 1: Embedded C - Parte 1/2")

    # Texto manuscrito do aluno Vicenzo
    add_body("No primeiro vídeo, o professor Marcelo começa explicando o porquê aprender C para sistemas embarcados exige mudar a forma de pensar dos programadores, apresentando a diferença essencial entre escrever um programa em C de forma tradicional no computador e escrever um programa em C em um microcontrolador, como no caso de uma placa STM32F103 Blue Pill. No caso dessas diferenças, é que no desktop o programa roda em cima de um sistema operacional, como Windows, Linux e afins. A linguagem C é usada para criar aplicativos de alto nível. O sistema operacional aloca a memória RAM virtualizada para o seu programa, isola o processo e gerencia os arquivos. Se o programa tentar acessar um endereço de memória que não é dele, o sistema operacional intervém e dispara um erro de segmentação.")

    add_body("Agora no caso de um sistema embarcado, o código roda direto na placa, então não tem essa rede de proteção, pois não tem a presença de um sistema operacional. O programador tem total controle e responsabilidade sobre o hardware e afins. É o programador que configura o clock, barramentos, direção de pinos de saída e entrada (GPIO), interrupções e afins, igual estamos fazendo na matéria.")
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

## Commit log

2026-07-31 Update: Added KiCad PCB, assembly photo, Python interface server and updated README
    [PCB_macropad-B_Cu.gbr, PCB_macropad-B_Mask.gbr, PCB_macropad-B_Paste.gbr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]
2026-07-31 Style: Cropped assembly photo to 3:4 aspect ratio and aligned image heights in README
2026-08-06 Refactor: Added LaTeX report relatorio_streamdeck.tex, RELATORIO_STREAMDECK_UFU.pdf, TIM2 Timer Interrupt firmware, single-layer thick trace PCB, and updated README
2026-08-06 Docs: Added detailed mechanical switch compatibility (Generic MX Blue 3-pin) to LaTeX and PDF reports
2026-08-06 Fix: Removed Bruna, fixed LaTeX cover formatting, fixed utf8 inputenc, and restored all original report sections
    [generate_pdf_report.py]
2026-08-06 Feat: Integrated assembled hardware updates (TIM2 ISR drivers, USB D+ reset, KiCad Gerber/PCB updates, and dashboard telemetry)
    [main.c, streamdeck bluepill.ioc]
2026-08-06 Docs: Updated relatorio_streamdeck.tex with side-by-side PCB subfigures and advanced firmware modifications (USB D+ reset, EPIN 8 bytes, DBGMCU sleep)
2026-08-06 Fix: Resolved text margin overflows with microtype and updated 3D PCB images side-by-side (top and bottom views)
    [generate_pdf_report.py]
2026-08-06 Docs: Embedded 2D KiCad single-layer trace layout image into Section 5.1 of LaTeX and PDF report
2026-08-06 Feat: Replaced primary PCB with PCB_FINAL KiCad files, added 3D STL enclosure files, and updated primary PDF report StreamDeck_SEMB.pdf
    [PCB_macropad-B_Cu.gbr, PCB_macropad-B_Mask.gbr, PCB_macropad-B_Paste.gbr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]
2026-08-07 Docs: Updated README.md with final prototype photos (Projeto Pronto and Montagem), TIM2 ISR architecture and KiCad PCB specs
2026-08-07 Docs: Removed KiCad PCB section from README.md as requested
2026-08-07 Docs & Repo: Added Bruna de Jesus Silva (12021ETE007) to team members and reorganized repository files
    [PCB_macropad-B_Cu.gbr, PCB_macropad-B_Mask.gbr, PCB_macropad-B_Paste.gbr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]

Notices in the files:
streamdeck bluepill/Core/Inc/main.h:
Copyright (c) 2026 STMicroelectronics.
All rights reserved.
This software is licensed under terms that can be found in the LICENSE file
